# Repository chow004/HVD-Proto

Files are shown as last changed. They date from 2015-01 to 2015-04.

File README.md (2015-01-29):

# HVD-Proto
HDMI Video Divider device prototype development. Copryright DigiPen Institute of Technology.

Project development for the HVD began September, 2014. The project is considered course work for ECE310L and ECE460L.
All submission should be organized into the following sections:

Documents - This section will contain technical documentation, presentation materials, and references used during development.

Hardware - This section contains files related to hardware development mainly including eagle files.

Software - This section sontains files related to software development mainly including code files.

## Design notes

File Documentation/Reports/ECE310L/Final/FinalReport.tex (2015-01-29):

\documentclass[pdftex,12pt,a4paper]{article}

\usepackage{graphicx}
\DeclareGraphicsExtensions{.jpg}
\usepackage{float}
\usepackage[labelfont=bf]{caption}

\frenchspacing

\newcommand{\HRule}{\rule{\linewidth}{0.5mm}}

\begin{document}
\input{./title.tex}

\pagebreak
\tableofcontents
\pagebreak

%ABSTRACT
\section{Abstract}
The HVD is designed to duplicate or spatially divide display data from any HDMI signal. The hardware requirements of the HVD and image processing required by the device design will benefit from the parallel processing offered by an FPGA platform\cite{TechDoc_FPGA_Benefits}.  Specifically, the HVD will be implemented with the Cyclone IV on the DE2-115 development board paired with HDMI interface solutions offered by Analog Devices\cite{DataSheet_ADV7611, DataSheet_ADV7513, Guide_ADV7611, Guide_ADV7513}. Development concerning the design and testing of the HDMI interface PCBs and I$^2$C communication will be covered by this paper. Due to the project goals remaining unachieved, evaluation concerning design progress and future planning is also presented. 

%INTRODUCTION
\section{Introduction}

\paragraph{}
As a student we have found FPGA development and communication protocols subject of our highest interests. FPGA devices can enable engineers to use hardware to implement software applications with less concern about application specific device processing constraints. FPGA's reconfigurablility provide system flexibility and adaptability during the design phase. They have no operating system system and use parallel processing paths, giving the designer control of the architecture for processing logic \cite{TechDoc_FPGA_Benefits}.

\paragraph{}
Communication protocols are a means of communicating data between two systems or to device peripherals. The protocols are standardized meaning peripheral devices can communicate with a variety of systems. Communication protocol are essential for several computer system and can vastly improve data processing. Advancements in display protocols in particular has refined how users observe video data. HDMI 2.0, for example, increased video resolution from 1080p to 2160p \cite{Web_HDMI_2.0}. Consumers can enjoy higher resolution images and higher video refresh rates partially due to improvements in protocols. Thus protocols can serve a pivotol role in technological advancement. 

\paragraph{}
With respect to our subjects of interest, FPGA development and protocols, we prepared a design for an FPGA device that primarily relies of communication protocol implementation. This device we came to call the HVD for HDMI Video Divider.As the name suggests, the device's end use will be to spatially divide an HDMI video frame and process each division for output. The HVD will be especially suited for split screen applications. The device implementation  consists of the base FPGA platform, HDMI interface, and I$^2$C driven system intercommunication. This document will overview the system design in detail, procedures used to test the system, and analyze the progress of the device's development within the first development cycle.

%END USER APPLICATION
\section{End User Application}

\paragraph{}
The HVD shall function given standard HDMI display data from any source. This flexibility allows the device implementation opportunities in various applications. Any other HDMI output capable product, such as a DVD player, computer, or video game console, will provide dual video data with the assitance of the HVD. The HVD will exist between the source and display mediums in an application setup. The source HDMI signal will enter the HVD device to be interpreted and optionally divided before duplicated display data or divided display data is sent to respective display mediums. Figure~\ref{fig:use} is a diagram of the theoretical HVD setup for a display divided across two mediums.

% FIGURE
\begin{figure}[H]
\centering
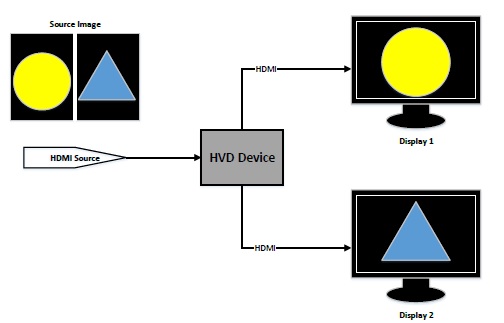
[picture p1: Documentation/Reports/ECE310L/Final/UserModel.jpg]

\caption{\textbf{Setup for dividing video across two display mediums using the HVD device}}
\label{fig:use}
\end{figure}

\paragraph{}
While the HVD can apply to an arbitrary HDMI source, the suitable applications for this device are more situational. For example, clients wouldn't have any need to divide a movie display across two TVs which may result in decreased video quality. All video applications do not benefit from the features the HVD offers, but several cases do. A split screen application has more obvious use for the HVD. Split screen  is a video technique in which the frames are spatially divided into discrete nonoverlapping images. Cooperative or comptetitve multiplayer video game applications can use this technique to incorporate multi-user designs. However, the nature of such a design allows players to 'screen peek,' a tactic where players might watch an opponent's screen to gain an unfair advantage. With the HVD, this situation can be prevented. Each user's portion of the display can be output to a separate video medium which can be moved to make the display more private to one of the users.

%SYSTEMS DESIGN
\section{Systems Design}

\paragraph{}
The HVD device requires the integration of several systems to provide complete functionality of the necessary features. This section cover the individual design and implementation of each of the HVD's major systems including the system platform, hdmi interface, and I$^2$C communications. Figure~\ref{fig:block} at the end of this section is a block diagram of the entire HVD system design.

%	FPGA PLATFORM
\subsection{FPGA Platform}

\paragraph{}
The Altera DE2-115 Development Board was selected as HVD's processing platform. Implementing the HVD on an FPGA was a easier design solution as opposed to finding an ASIC development solution that matched all the design constraints. These design constraints include support for three HDMI ports and high speed video processing. An FPGA design is suitable for the HVD's design because the highly parallel architecture they offer meet the HDMI performance requirements\cite{TechDoc_FPGA_Benefits}. The DE2-115 digital logic is programmed using the Verilog hardware descriptive language compiled and developed with Altera's toolchain, Quartus II. 

\paragraph{}
Using the DE2-115 ensures we can implement a solution for the HVD design requirements. The on-board 50 MHz clock and PLL clock generator enables the FPGA to process the high speed HDMI . The board does have SDRAM and SRAM, but these memory implementations have insufficient bandwidth to store the data fast enough\cite{UserManual_DE2}. Therefore, we will store data using the Cyclone IV FPGA embedded memory M9K blocks. The M9K blocks features configurable data width and dual-port modes necessary for storing pixel data at the required speeds\cite{TechDoc_M9K}. The HDMI protocol support a pixel clock up to 165 MHz at a resolution of 24 bits per pixel, resulting in the necessity to simultaneously read and write data at almost 4 Gbps\cite{TechDoc_HDMI_Spec}.

\paragraph{}
While the DE2-115 does not provide an HDMI interface solution, the HSMC is a high-speed header that can provide a sufficient amount of GPIO lines to the Cyclone IV for our own integration of an HDMI interface. Paired with the a Terasic GPIO Daughter Board, we HSMC connects to three more GPIO headers\cite{UserManual_THDB-HTG} which can be used to communicate with three HDMI interfaces.

%	HDMI Interface
\subsection{HDMI Interface}

\paragraph{}
The HDMI interface will be implemented using Analog Devices chip solutions. The ADV7611 implements HDMI receiving interface while two ADV7615 will implement each HDMI transmission interface. The HDMI receiver interface translates the differential signals from an HDMI source into 24 parallel pixel data signals\cite{DataSheet_ADV7611}. Audio data is also provided and interpreted by the HDMI interface but is not being implemented in HVD version 1.0. The transmitter interfaces translates 24 parallel pixel data lines into differential signals\cite{DataSheet_ADV7513}. The chips are configured through their main I$^2$V ports which control registers and protocol data such as the info frame or extended display identification data, EDID. Protocol information is essential for identifying and controlling the HDMI configuration of the source device\cite{TechDoc_HDMI_Spec}.

%	SYSTEM COMMUNICATIONS
\subsection{Communications}

\paragraph{}
The DE2-115 must establish communication with the HDMI interfaces. There will be an I$^2$C protocol port generated using the FPGA's digital logic for each interface. The logic of the Verilog module for the I$^2$C protocol is implemented using a finite state machine architecture. The I$^2$C module generates the protocol's serial clock of approximately 390 KHz from the 50 MHz main clock on the DE2-115. The module's logic is handled in two major blocks functioning off of a logic clock and serial clock. State machine transition and serial data is processed on the logic clock while serial clock ticks and byte transaction and processed on the serial clock. The logic and serial clock are generated so that a logic process step will execute between each serial clock cycle so that the data line is correctly set before the serial clock indicates data is valid on the bus. Figure~\ref{fig:sm} shows the state diagram for the I$^2$C module. Both logic block functionality are dependent on this state machine.

% FIGURE
\begin{figure}[H]
\centering
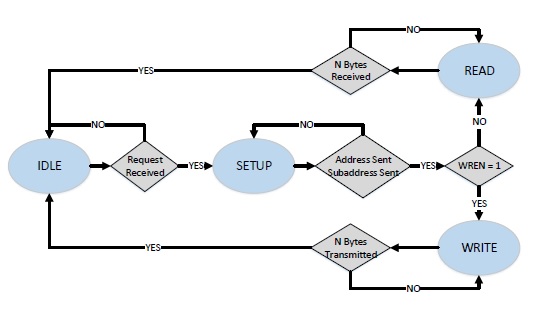
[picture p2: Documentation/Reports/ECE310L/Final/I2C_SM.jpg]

\caption{\textbf{I$^2$C module finite state machine}}
\label{fig:sm}
\end{figure}

\paragraph{}
The Cyclone IV FPGA acts as the master in the I$^2$C protocol while each register map on the HDMI interfaces are slaves. Since each HDMI interface will have its own dedicated I$^2$C port we can assume the default slave address configurations on each interface.  Each slave device is accessed with a 7-bit address, a R/W bit indicating the nature of the transaction, and an 8-bit sub-address within the register map. The read and write procedures for the HDMI receiver are depicted in Figure~\ref{fig:i2c}\cite{Guide_ADV7611}. The HDMI transmitter is programmed via I$^2$C in the same manner with different register maps.

% FIGURE
\begin{figure}[H]
\centering
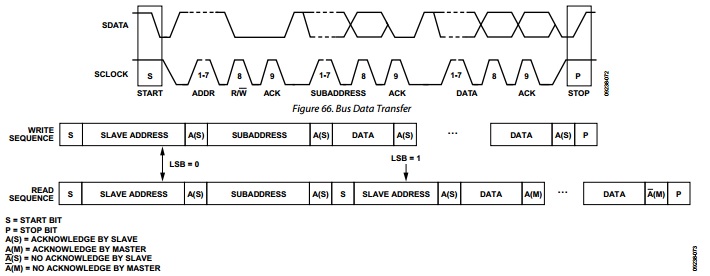
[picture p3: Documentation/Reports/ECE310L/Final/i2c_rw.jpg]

\caption{\textbf{I$^2$C read and write sequence and bus data signaling. An ACK is indicated by pulling the SDATA line low and a NACK is indicated by pulling the SDATA line high.}}
\label{fig:i2c}
\end{figure}

%	PCB INTEGRATION
\subsection{PCB Integration}

\paragraph{}
To integrate the HDMI interfaces with the DE2-115 the HDMI chips must be housed on a PCB to interface with small chip package. Each HDMI interface PCB will connect to the DE2-115 through a GPIO header on the HSMC to GPIO daughter board. Eagle schematics for the HDMI receiver PCB are located in hdmi\_receiver.sch. Care was taken to include several termination resistors and decoupling capacitors in order to maintain the interface system stability. A 3-layer PCB was design with an internal GND plane and percautions were taken to keep the HDMI differential signals parallel and similar in length. The HDMI transmitter PCBs will have a similar design to the HDMI receiver PCB. Having separate PCB designs for the transmitter and receivers provides individual control over each interface and may simplify component upkeep with separated designs.

%	BLOCK DIAGRAM
\subsection{Block Diagram}

% FIGURE
\begin{figure}[H]
\centering
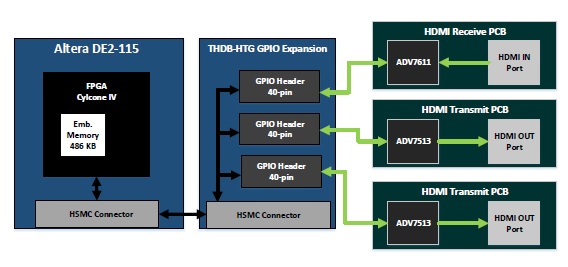
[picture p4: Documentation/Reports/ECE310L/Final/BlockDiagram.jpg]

\caption{\textbf{HVD systems block diagram}}
\label{fig:block}
\end{figure}

%RESULTS
\section{Results}

%	TIMELINE
\subsection{Timeline}

The past development cycle for the HVD is illustrated in the timeline in Figure~\ref{fig:time}.

% FIGURE
\begin{figure}[H]
\centering
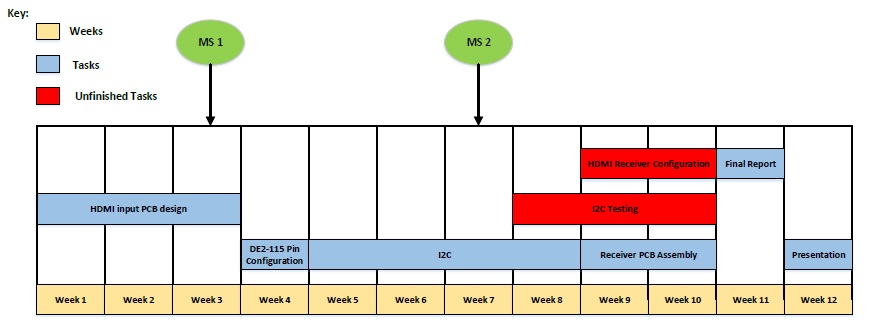
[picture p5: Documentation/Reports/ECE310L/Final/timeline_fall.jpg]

\caption{\textbf{Development timeline}}
\label{fig:time}
\end{figure}

%	HDMI RECEIVE INTERFACE
\subsection{HDMI Receive Interface}

\paragraph{}
This development cycle focused on the HDMI receive interface implementation including the PCB design, testing, and DE2-115 I$^2$C communication. The receiver was developed first in order to avoid unnecessary development requirements to test the HDMI interface. Ideally to test the HDMI transmit functionality we would ultimately want to transmit a video frame. Instead of having the FPGA generate a video frame, establish a the receiver to acquire a frame instead for later output reduced the software development.

\paragraph{}
The eagle design files for the HDMI receiver PCB are hdmi\_receiver.sch and hdmi\_receiver.brd. This prototype serve as a sufficient test board for identifying early design errors. One such error was already discovered; the footprint for the DC power jack is incorrect making the barrel receptacle impossible to solder to the board without modifications. Further testing is required to verify the functionality of this board which wasn't achieved during this development cycle.

%	I2C PROTOCOL
\subsection{I$^2$C Protocol}
The I$^2$C protocol is essential for controlling the HDMI receive interface using the DE2-115. The I$^2$C module was implemented in Verilog and tested through several mediums. First, Alter'a ModelSim IDE was used to verify the module could be instantiated and successfully produce the desired waveforms in simulation. The real signal generation of the module was observed and checked using oscilloscopes. Some oscilloscope waveform samples are shown and described in Figures~\ref{fig:osc_tx} and~\ref{fig:osc_rx}. This also verified that the pin configurations over the HSMC to GPIO daughter board were correct and functional. Finally, Link Instruments MSO-19.2 with a built in I$^2$C protocol interpreter was used to confirm the I$^2$C module signals were successfully interpreted to comply to the I$^2$C standard. 

% FIGURE
\begin{figure}[H]
\centering
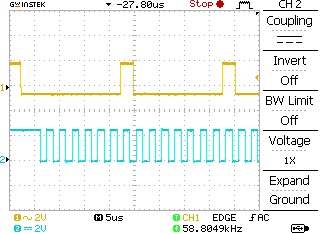
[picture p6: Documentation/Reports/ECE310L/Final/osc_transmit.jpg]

\caption{\textbf{Screen captured from oscilloscope reading I$^2$C data. The top signal is the SDA and the bottom is SCL.A write sequence is depicted in the captured image. First the SDA is pulled low while the SCL signal is high to indicate a START condition. This enable the generated of the I$^2$C serial clock signal which SCL is connected to. The first data transmitted across the SDA line is the slave address, which in this case is 0x1 in 7-bits. After the 7th bit is transmitted the R/W bit which is zero for a write sequence is sent. On 9th the SCL clock pulse, the SDA line is set to high impedance to acquire an acknowledge input from the slave device. In this case, there is no slave device connected so the SDA remains unchanged. Afterward the subaddress 0x4 is sent in 8-bits in the same fashion. }}
\label{fig:osc_tx}
\end{figure}

% FIGURE
\begin{figure}[H]
\centering
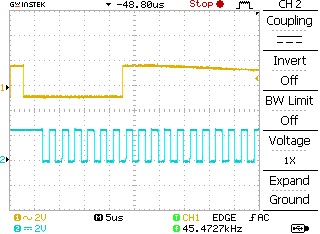
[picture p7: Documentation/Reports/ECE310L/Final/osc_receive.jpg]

\caption{\textbf{Screen captured from oscilloscope reading I$^2$C data. The top signal is the SDA and the bottom is SCL.A read sequence is depicted in the captured image. Before a read transaction, the subaddress pointer must be set by a previous write transaction. First the SDA is pulled low while the SCL signal is high to indicate a START condition. The first data transmitted across the SDA line is the slave address, which in this case is 0x1 in 7-bits. After the 7th bit is transmitted the R/W bit which is one for a read sequence is sent. ON the 9th SCL clock pulse, the SDA line is set to high impedance to acquire an acknowledge input from the slave deivce. In this case, there is no slave device connected so the SDA remains mostly unchanged. Afterwards the SDA remains set to high impedance to accept input on the SDA line. The SDA line is then only controlled by the master when asserting an ACK or NACK. This signal receives no input but because the SDA line is left at high impedance there is a noticeable decay in the signal. }}
\label{fig:osc_rx}
\end{figure}

\paragraph{}
The simulation and oscilloscope tests and check were successful but the test data offered by the MSO-19.2 gave questionable data that didn't completely confirm our I$^2$C module conformity to the standard protocol. A lack of explicit documentation on the data presented by the I$^2$C interpreter user interface, incorrect signal timing values, and some unexpected protocol behavior makes it so the test in not a perfect verification of the I$^2$C protocol correctness. A sample of MSO-19.2 data is shown and described in Figure~\ref{fig:mso}.

% FIGURE
\begin{figure}[H]
\centering
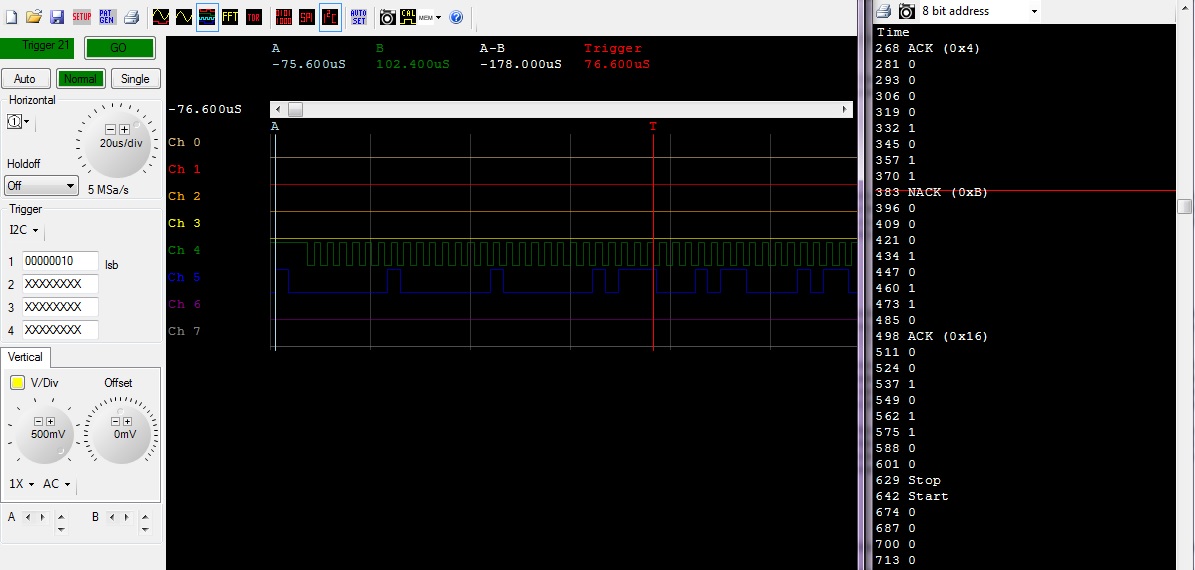
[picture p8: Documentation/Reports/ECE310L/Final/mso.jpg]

\caption{\textbf{This is MSO data from an I$^2$C write sequence. Channel 4 is the SCL signal and Channel 5 is the SDA signal. The I$^2$C interpreted data is shown in a console window to the right. Start and Stop condition are detected successfully. The data bytes represented in the console window are also correct. However the timing units in microseconds are for some reason off by a factor of 10. Each clock cycle should take approximately 2.5 microseconds while the MSO data shows approximately 25 microseconds. There also is a matter concerning the NACK. The MSO interpeter should generate acknowledge signal for valid I$^2$C data but after receiving a 0xB data byte in this case it generated a NACK. The cause for this is unknown. }}
\label{fig:mso}
\end{figure}

%ANALYSIS
\section{Analysis}

%	TESTING
\subsection{Testing}

\paragraph{}
The HDMI receiver PCB and I$^2$C protocol tests are largely incomplete. The goal for integrated these two systems was also not achieved. Some lack of development foresight in development time led to delays and deviation from the original time line became inevitable. Since the I$^2$C protocol correctness isn't completely verified, we will have to examine if its current implementation is able to properly communicate with the HDMI receive PCB. Examining the functionality of the PCB, ADV7611 HDMI receiver, and the correctness of the I$^2$C protocol at the same time can lead to difficult debugging scenarios involving multiple variables. Unless more investment is made to further test the I$^2$C protocol with additional testing hardware, the cluttered testing scenario may be inevitable.

%	DEVELOPMENT TIME
\subsection{Development Time}

\paragraph{}
Setbacks in the initial development cycle will propagate through to the next. Expected project goals must be re-evaluated. It is an end design goal to be able to process and divide a single HDMI signal into two separate signals. In order to fully implement the hardware and integrate the system, time to development image processing requirements may be sacrificed. The image processing logic, while it is an essential part of the HVD's ideal application, must be the first feature to be dropped from expected implementations in the next development cycle because it reliant on functioning hardware and complete system integration. A proposed time line for next development cycle is shown in Figure~\ref{fig:newtime}. Notice that there is no time reserved for the image processing algorithms necessary for the HVD goal application.

% FIGURE
\begin{figure}[H]
\centering
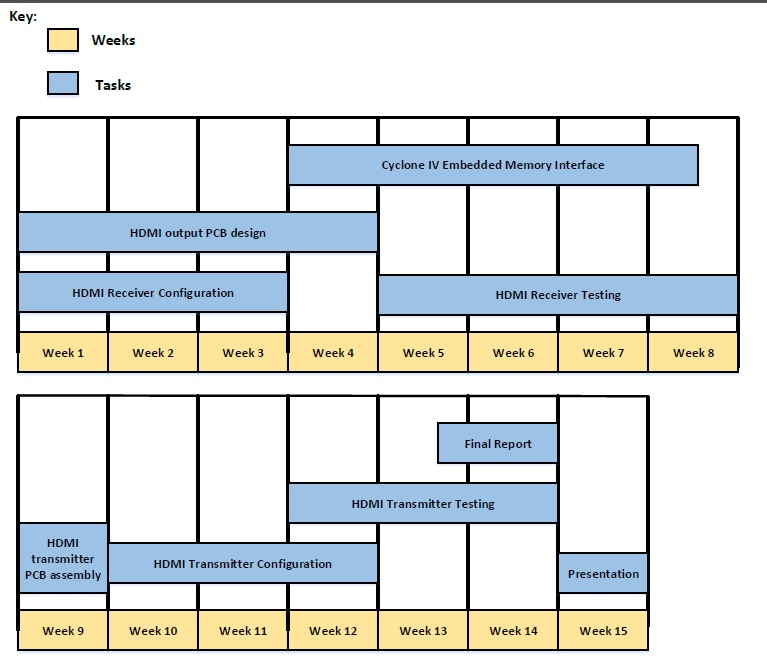
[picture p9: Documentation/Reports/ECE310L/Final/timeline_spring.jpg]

\caption{\textbf{Next cycle development timeline}}
\label{fig:newtime}
\end{figure}

%	BUDGET
\subsection{Budget}

\paragraph{}
The cost reports for this development cycle was rather high. The PCB fabrication expense for HDMI receiver consumed most of the allowed budget. In order to improve the HVD cost efficiency, future versions should be reduced from a 3-layer to 2-layer board. This will present more design constraints in order to ensure signal integrity. Examining current design faults in the HDMI receive PCB will lend insight when designing the HDMI transmit PCB.

%CONCLUSION
\section{Conclusion}

\paragraph{}
Results of this development cycle are less than optimal. Several pivitol tasks and goals that were not completely satisfied and others were pushed back resulting. However, steady though unideal progress on the development of the HVD systems has deviated little from the original implementation designs. We are confident that the design plans for the HVD remains sound.

\paragraph{}
Overall, the major systems that were suppose to be complete within this cycle still need to be verified and tested. Once all the issues are determined, they can be addressed in future design iterations. While development on the HDMI transmit interface was never achieved, it's similarity to the HDMI receive interface means and problems encountered in devloping the receiver can be avoided when designing the transmitter. The I$^2$C protocol module on the DE2-115 will also function in communication with the transmitter. 

\paragraph{}
In the following cycle, once the previous tasks are completed. A quick rework of the receiver PCB, prototype of the transmitter PCB and I$^2$C integration should be achievable. The remaining time can be spent working on the HDMI configuration software and memory logic on the Cyclone IV. The image processing development has been delayed, but focus on the HVD hardware and interface systems is an absolute priority.

\pagebreak
%ACKNOWLEDGEMENTS
\section{Acknowledgements}

\paragraph{}
We would like to acknowledge the following persons, whose contributions and guidance made the development and execution of this project possible.
\newline
\newline
Lukas van Ginneken for instructing and assisting in planning the project, identifying design constraints, and providing development solutions. Jeremy Thomas for instructing, offering guidance on engineering practices, and encouragement that helped keep us motivated. Christopher Theriault for managing the project budget, acquiring necessary resources, and providing test tools. Nicholas Rivera for sharing his experience and knowledge in embedded systems designs. And Johnny Sim for sharing his experience and knowledge of Altera's FPGA development software.
\newline
\newline
Thank you for all of your support.

%References
\bibliographystyle{ieeetr}
\bibliography{Citation}

\end{document}

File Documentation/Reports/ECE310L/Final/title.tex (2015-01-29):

\begin{titlepage}
\begin{center}

%Title
\HRule \\[0.5cm]
{\huge \bfseries HVD-1\\[0.5cm]}
\HRule \\[1.0cm]

\textsc{\LARGE HDMI Video Divider ver 1.0}\\
[1.5cm]

%Engineers
\begin{minipage}{0.9\textwidth}
\begin{flushleft} \large
{\bfseries Engineer:}\\
\emph{Cassandra \textsc{Chow}}
\end{flushleft}
\end{minipage}
%Instructors
\begin{minipage}{0.9\textwidth}
\begin{flushright} \large
{\bfseries Instructors:}\\
\emph{Lukas \textsc{van Ginneken}}

\emph{Jeremy \textsc{Thomas}}

\emph{Christopher \textsc{Theriault}}
\end{flushright}
\end{minipage}

\vfill

%Bottom of Page
{\large DigiPen Institute of Technology}\\
{\large Department of Computer Engineering}\\
{\large ECE 310L, Fall 2014}\\
{\large Revision: 1.0}

\end{center}
\end{titlepage}

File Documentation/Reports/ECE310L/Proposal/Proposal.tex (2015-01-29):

\documentclass[12pt]{article}
\pagestyle{plain}
\linespread{2}

% Document
\title{HDMI Divider}
\author{Cassandra Chow}

% Declarations
\usepackage{graphicx}
\DeclareGraphicsExtensions{.jpg}

\frenchspacing
\usepackage{indentfirst}
\usepackage{fullpage}
\usepackage{float}

\begin{document}
\maketitle

% ABSTRACT
\begin{abstract}
With the detailed project we will strive to design an embedded system that will enable the user to divide a primary high-definition multimedia interface (HDMI) display source into two separate outputs that each display half of the primary display. The application of this device if focused at enabling video game players to assign parts of the game display to other dedicated displays which can be useful for multiplayer games designed with split-screen gameplay. To do this, our product will need to accept HDMI input frames, divide that input into two separate output frames, and process the output frame to suit their individual displays. 
\end{abstract}

\pagebreak
\tableofcontents

% INTRODUCTION
\pagebreak
\section{Introduction}

Our product, which we will call an HDMI Divider for now, will be designed to give its user a solution to dividing split-screens that is not otherwise offered by the application or display hardware itself. The application of the HDMI splitter is illustrated in Figure~\ref{fig:concept}. Because the HDMI divider will be able to accept HDMI signals from an arbitrary source device, it's application can be utilized across any platform using HDMI output. Giving consumers the option of dividing their display can enhance the experience of video game players especially in competitive gameplay. Where players are competing, it is in the best interest of each user to win against the other in some manner but a split-screen setup prevents the players from concealing their actions from the other. Another reason players might find this device attractive is just the ability to expand their split portion of the screen to a larger display.

\begin{figure}[H]
\centering
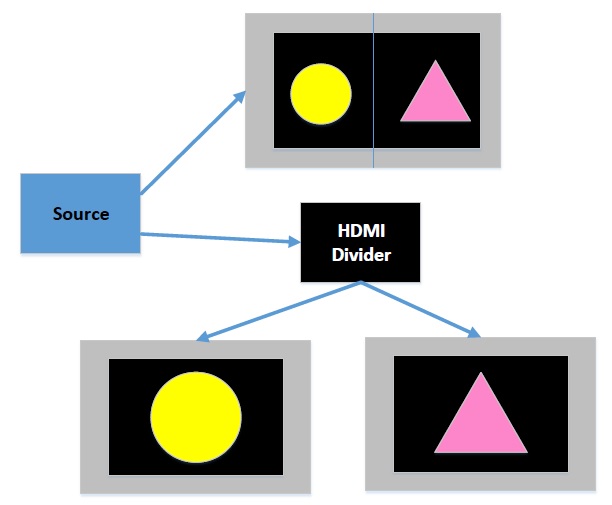
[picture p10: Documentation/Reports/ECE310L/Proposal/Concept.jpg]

\caption{Represents use model concept of the HDMI divider dividing a split-screen into two dedicated displays}
\label{fig:concept}
\end{figure}

This project also acts as a challenging learning experience to an undergraduate student. Since we will be utilizing the digital logic on a field-programmable gate array (FPGA) to accomplish our device implementation, we will not only become more familiar with FPGA applications but also obtain a better grasp on embedded system architecture and the HDMI protocol specification. Most projects of interest to us required in-depth knowledge in protocols that are widely used in various electronics, therefore a project which includes development on the HDMI is the main reason for undertaking this task. All of the above benefits will be sought out in order to improve our design capabilities as an engineer. 

% METHODS, TECHNIQUES, and DESIGN
\section{Methods, Techniques, and Design}

% DESIGN CONSIDERATIONS
\subsection{Design Considerations}

To understand the requirements for our project we must examine our resource requirments which includes knowing what data we are acquiring, how the data is being acquired, and what our device will do with that data. For our application model we will require the display data from some external source which will be transmitted via the HDMI interface. The received display data must be processed and then output across two individual displays. Our target display format is the standard HDTV configuration which supports a resolution of 1920x1080p. The platform we decided on to implement our design is an FPGA. FPGAs are known for being able to perform signal processing quickly which is critical in display applications. The specific development platform we will be using is Altera's DE2-115 Development and Education board.The DE2 provides us with sufficient means in accomplishing our project requirements while also being flexible to future changes.

% HDMI DISPLAY
\subsection{HDMI Display}

According to the HDMI specification, there are three data channels used to transmit pixel data typically at a resolution of 24 bits per pixel, 8 bits per channel. The HDMI interface has a pixel clock that functions at a maximum of 165 MHz \cite{Ref_HDMI_Spec}. The DE2 can support the necessary switching speed on it's I/O lines but the on-board SRAM and SDRAM have insufficient bandwidth capabilities to store the data fast enough. We will therefore be writing to the embedded memory on the FPGA chip allowing us to take advantage of the speed capabilities on the FPGA. There are only 486 Kbytes of embedded memory on the Cyclone IV DE2 FPGA chip \cite{Ref_Memory_Block}, so we cannot store entire frames but this is sufficient space to store the each line of data for each input and output frame until it it is processed. Then by using a simple image rescaling algorithm, such as nearest neighbor or interpolation, we can als ensure we are able to resize the image properly even if we cannot send and receive an entire frame at once.

There is no onboard solution for implementing the HDMI protocol on the DE2 board, therefore we will being using HDMI transmitter and HDMI receiver chipsets. Each selected chipset requires approximately 32 I/O lines \cite{Ref_HDMI_Rx} to interface with the DE2 but the DE2 board only has 36 GPIO pins mapped to the the Cyclone IV \cite{Ref_DE2}. However, we can expand the number of GPIO pins available by connection an expansion board to the DE2's High-Speed Mezzanine Connector (HSMC), giving us access to another three GPIO headers. Since we only need 3 HDMI interface, 1 input and 2 outputs, we will only have enough GPIO pins available if we use the HSMC GPIO expansion daughter card. To implement the HDMI chipsets and connection, we'll be designing a PCB for each to interface with the DE2 though the GPIO expansion. Our implementation for our device is illustrated by the system block diagram in Figure~\ref{fig:block}.

\pagebreak

% BLOCK DIAGRAM
\subsection{System Block Diagram}

\begin{figure}[H]
\centering
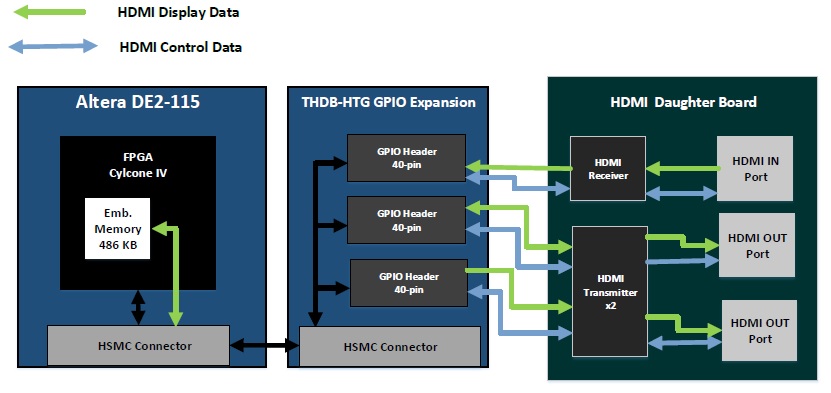
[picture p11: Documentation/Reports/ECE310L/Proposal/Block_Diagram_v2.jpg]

\caption{Block Diagram of device implementation}
\label{fig:block}
\end{figure}

\pagebreak

% PARTS LIST
\section{Parts List}

These are the primary components required for our HDMI Divider implementation

\begin{itemize}
\item Altera DE2-115 Education and Development Board \cite{Ref_DE2}
\item THDB-HTG GPIO daughter board \cite{Ref_GPIO_daughter}
\item ADV7611 HDMI Receiver \cite{Ref_HDMI_Rx}
\item AD9389B HDMI Transmitter x2 \cite{Ref_HDMI_Tx}
\end{itemize}

% TIMELINE
\section{Timeline}

Figure~\ref{fig:timeline} is the task timeline we have set for ourselves over the next 12 weeks of development. By the end of 12 weeks we should be able to confirm HDMI input and output functionality including the memory architecture requirements. Notice that we are not going to be working on the image processing required for dividing and resizing the display output yet, just establishing the protocol functionality on the FPGA.

\begin{figure}[H]
\centering
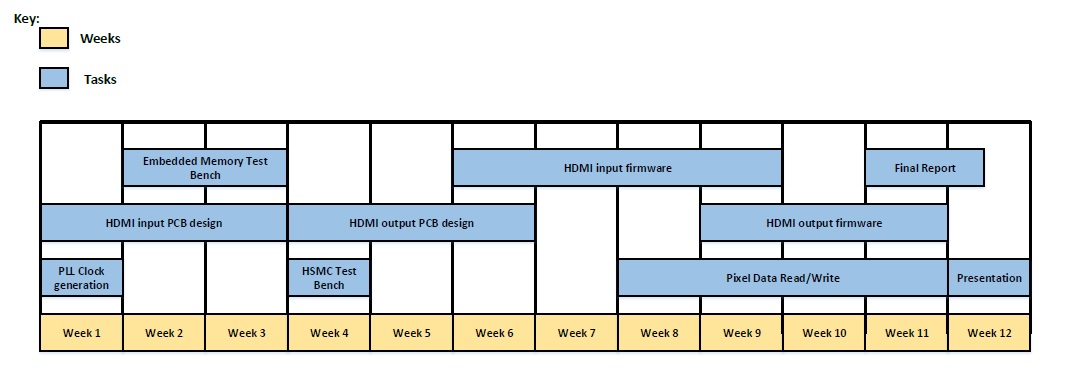
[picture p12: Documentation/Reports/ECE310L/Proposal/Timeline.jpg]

\caption{Timeline for development tasks}
\label{fig:timeline}
\end{figure}

\begin{description}
\item[PLL Clock Generation] Configuring the PLL on the FPGA to generate desired clock rates for processing
\item[HDMI Input PCB Design] Designing the PCB for the daughter card implementing the HDMI input port and interface
\item[HDMI Output PCB Design] Designing the PCB for the daughter card implementing the HDMI output port and interface
\item[Embedded Memory Test Bench] Configuring embedded memory system and testing read/write functionality
\item[HSMC Signal Test Bench] Configuring signal I/O over the HSMC to GPIO bus and testing functionality
\item[HDMI Input Firmware] Developing FPGA digital logic for receiving HDMI display data
\item[HDMI Output Firmware] Developing FPGA digital logic for transmitting HDMI display data
\item[Pixel Data Read/Write] Developing the read/write process for storing display data in memory
\item[Final Report] Compiling final project results into a report document
\item[Presentation] Preparing and delivering presentation of project results
\end{description}

\section{Citation}
\bibliographystyle{plain}
\bibliography{Citation}

\end{document}

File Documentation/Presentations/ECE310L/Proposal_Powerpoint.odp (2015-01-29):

## FPGA HDMI Display Divider

DigiPen Institute of Technology

Fall 2014

ECE 310L

Presented by Cassandra Chow

## Project Goals

- Learning FPGA architecture and application
- HDMI Protocol
  Mission Statement:
  To create a device that enables the user to divide their HDMI display into separate parts and delegate to these parts their own dedicated displays.

## High Concept

## Split-screen display

## Two dedicated displays

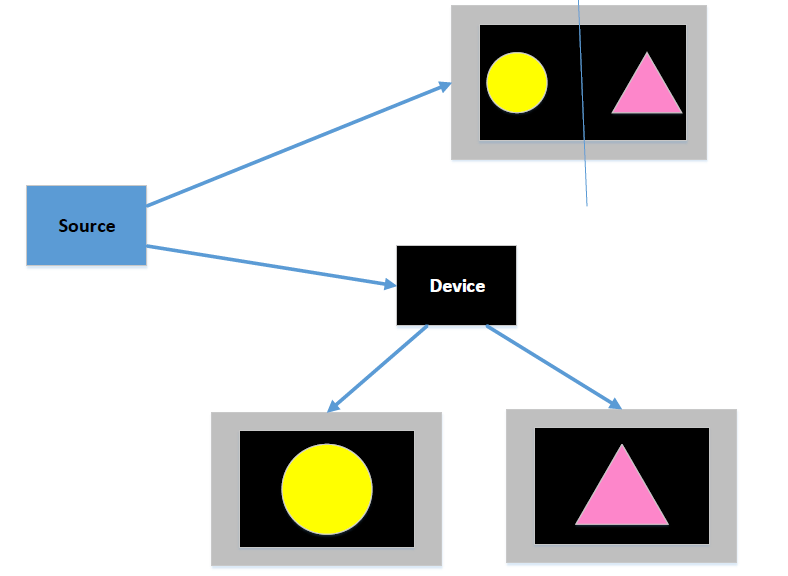
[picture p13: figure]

## FPGA Platform

- High speed video processing
- A little processing on a lot of data
- Requires building of analog components from scratch.

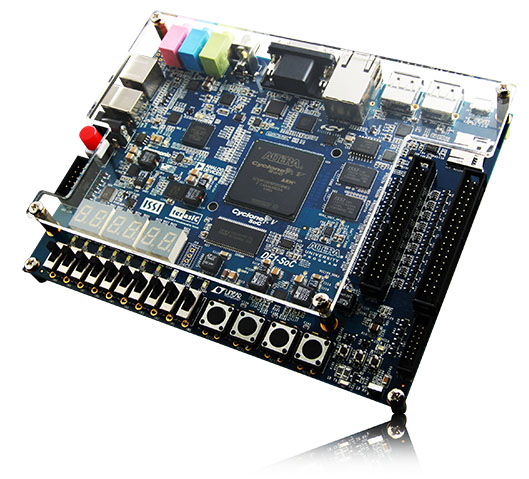
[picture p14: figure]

## HDMI Differential Signaling

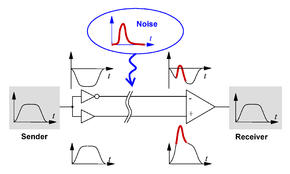
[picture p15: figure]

## Device Design

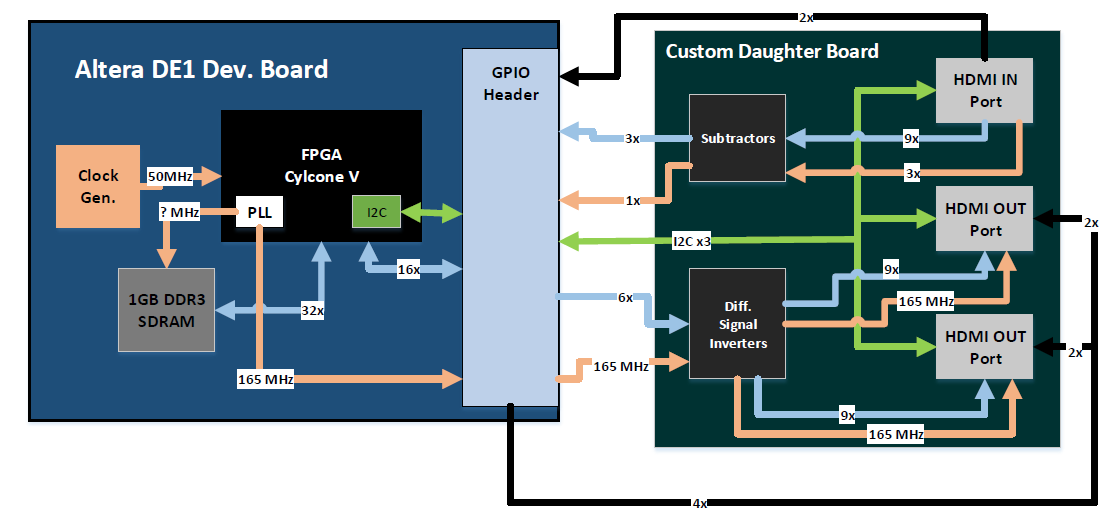
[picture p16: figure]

## Time Line (13 weeks)

- PLL & DDR3 SDRAM firmware (2 weeks)
- HDMI output prototype & firmware (2 weeks)
    > Debugging & Testing (1 week)
- HDMI input prototype & firmware (2 weeks)
    > Debugging & Testing (2 weeks)
- PCB design & fabrication (2 weeks)
- Final Report & Polish ( 2 weeks)

## Questions?

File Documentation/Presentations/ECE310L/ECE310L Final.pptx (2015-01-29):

## HDMI Video Divider HVD-1

DigiPen Institute of Technology
Fall 2014
Cassandra Chow

## Project Motivations

- FPGA Development
- Hardware implementation of software
- Reconfigurable
- Communication Protocols
- Rules that define format of data exchanges

## Project Concept

- An FPGA based device designed to duplicate or spatially divide display data from any HDMI signal

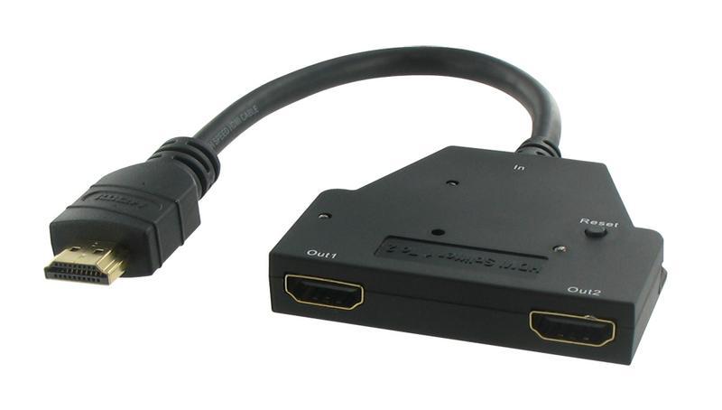
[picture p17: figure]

## HVD Use Model

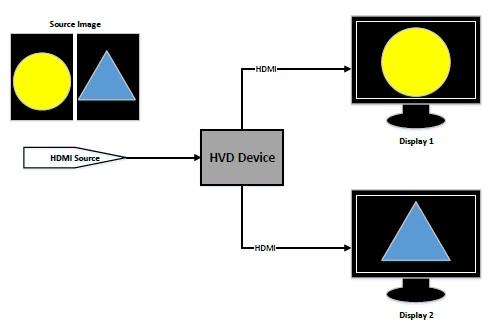
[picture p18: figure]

## Implementation

- Altera DE2-115
- Analog Devices HDMI Interface ASIC
- HSMC to GPIO daughter board
- I2C protocol intercommunication

## System Block Diagram

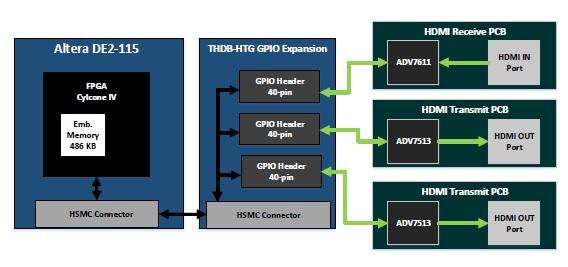
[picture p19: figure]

## I2C Communication

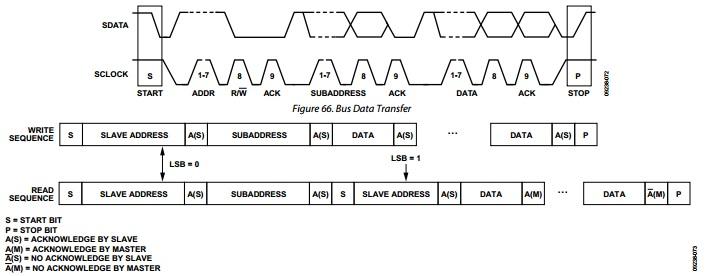
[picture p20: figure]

## I2C as a Finite State Machine

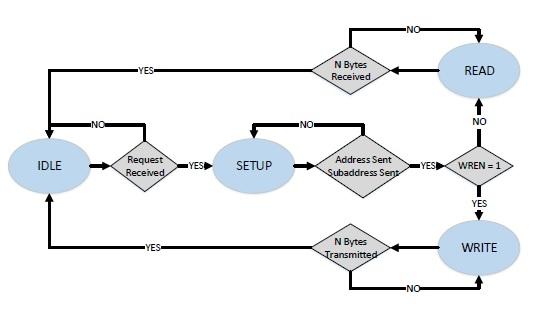
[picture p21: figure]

## Develop, Test, Debug

- Quartus II, Verilog HDL
- ModelSim waveform view
- Oscilloscope Tests
- MSO protocol interpreter

## Oscilloscope Test Data

Write Read

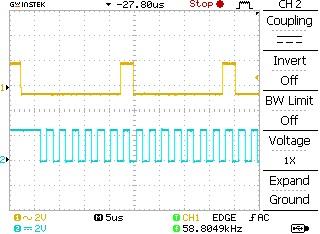
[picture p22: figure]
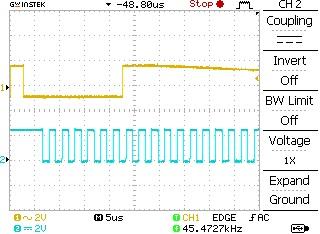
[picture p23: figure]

## MSO Test Data

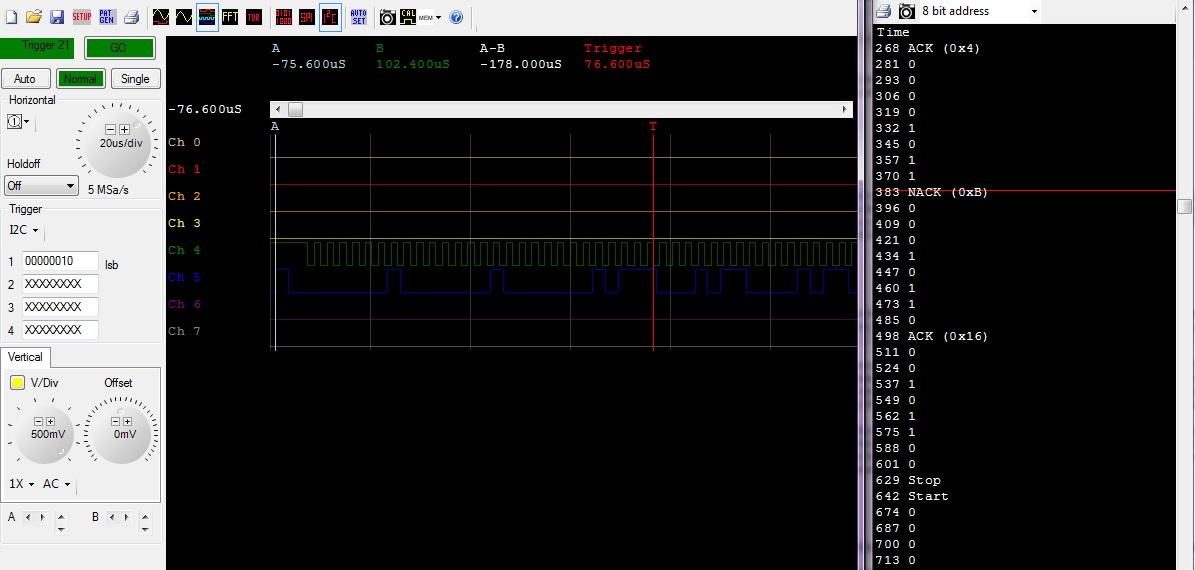
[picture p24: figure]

## HDMI Receiver PCB

- Eagle

## System Integration

- Requires verifying I2C communication
- Points of uncertainty hinder testing
Possible bugs
- I2C is incorrect
- PCB is flawed

Debug Solution: Acquire reliable I2C source

## Fall Timeline


## Next Semester

- Test and Debug
- HDMI Transmitter PCB
- DE2-115 Memory Interface
- HDMI Receive/Transmit Software

## Acknowledgements

- Lukas van Ginneken
- Jeremy Thomas
- Christopher Theriault
- Nicholas Rivera
- Johnny Sim

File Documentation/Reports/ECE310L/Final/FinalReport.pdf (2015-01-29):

# HVD-1

HDMI Video Divider ver 1.0

### Engineer: Cassandra Chow Instructors:

Lukas van Ginneken

### Jeremy Thomas Christopher Theriault

### DigiPen Institute of Technology Department of Computer Engineering ECE 310L, Fall 2014 Revision: 1.0

## Contents

1 Abstract | 2
2 Introduction | 2
3 End User Application | 3
4 Systems Design | 4
5 Results | 8
6 Analysis | 12
7 Conclusion | 14
8 Acknowledgements | 15

1

## 1 Abstract

The HVD is designed to duplicate or spatially divide display data from any HDMI signal. The hardware requirements of the HVD and image processing required by the device design will benefit from the parallel processing offered by an FPGA platform[1]. Specifically, the HVD will be implemented with the Cyclone IV on the DE2-115 development board paired with HDMI interface solutions offered by Analog Devices[2, 3, 4, 5]. Development concerning the design and testing of the HDMI interface PCBs and I²C communication will be covered by this paper. Due to the project goals remaining unachieved, evaluation concerning design progress and future planning is also presented.

## 2 Introduction

As a student we have found FPGA development and communication protocols subject of our highest interests. FPGA devices can enable engineers to use hardware to implement software applications with less concern about application specific device processing constraints. FPGA’s reconfigurablility provide system flexibility and adaptability during the design phase. They have no operating system system and use parallel processing paths, giving the designer control of the architecture for processing logic [1].

Communication protocols are a means of communicating data between two systems or to device peripherals. The protocols are standardized meaning peripheral devices can communicate with a variety of systems. Communication protocol are essential for several computer system and can vastly improve data processing. Advancements in display protocols in particular has refined how users observe video data. HDMI 2.0, for example, increased video resolution from 1080p to 2160p [6]. Consumers can enjoy higher resolution images and higher video refresh rates partially due to improvements in protocols. Thus protocols can serve a pivotol role in technological advancement.

With respect to our subjects of interest, FPGA development and protocols, we prepared a design for an FPGA device that primarily relies of communication protocol implementation. This device we came to call the HVD for HDMI Video Divider.As the name suggests, the device’s end use will be to spatially divide an HDMI video frame and process each division for output. The HVD will be especially suited for split screen applications. The device implementation consists of the base FPGA platform, HDMI interface, and I²C driven system intercommunication. This document will overview the

2

system design in detail, procedures used to test the system, and analyze the progress of the device’s development within the first development cycle.

## 3 End User Application

The HVD shall function given standard HDMI display data from any source. This flexibility allows the device implementation opportunities in various applications. Any other HDMI output capable product, such as a DVD player, computer, or video game console, will provide dual video data with the assitance of the HVD. The HVD will exist between the source and display mediums in an application setup. The source HDMI signal will enter the HVD device to be interpreted and optionally divided before duplicated display data or divided display data is sent to respective display mediums. Figure 1 is a diagram of the theoretical HVD setup for a display divided across two mediums.


Figure 1: Setup for dividing video across two display mediums using the HVD device

While the HVD can apply to an arbitrary HDMI source, the suitable applications for this device are more situational. For example, clients wouldn’t have any need to divide a movie display across two TVs which may result in decreased video quality. All video applications do not benefit from the

3

features the HVD offers, but several cases do. A split screen application has more obvious use for the HVD. Split screen is a video technique in which the frames are spatially divided into discrete nonoverlapping images. Cooperative or comptetitve multiplayer video game applications can use this technique to incorporate multi-user designs. However, the nature of such a design allows players to ’screen peek,’ a tactic where players might watch an opponent’s screen to gain an unfair advantage. With the HVD, this situation can be prevented. Each user’s portion of the display can be output to a separate video medium which can be moved to make the display more private to one of the users.

## 4 Systems Design

The HVD device requires the integration of several systems to provide complete functionality of the necessary features. This section cover the individual design and implementation of each of the HVD’s major systems including the system platform, hdmi interface, and I²C communications. Figure 4 at the end of this section is a block diagram of the entire HVD system design.

### 4.1 FPGA Platform

The Altera DE2-115 Development Board was selected as HVD’s processing platform. Implementing the HVD on an FPGA was a easier design solution as opposed to finding an ASIC development solution that matched all the design constraints. These design constraints include support for three HDMI ports and high speed video processing. An FPGA design is suitable for the HVD’s design because the highly parallel architecture they offer meet the HDMI performance requirements[1]. The DE2-115 digital logic is programmed using the Verilog hardware descriptive language compiled and developed with Altera’s toolchain, Quartus II.

Using the DE2-115 ensures we can implement a solution for the HVD design requirements. The on-board 50 MHz clock and PLL clock generator enables the FPGA to process the high speed HDMI . The board does have SDRAM and SRAM, but these memory implementations have insufficient bandwidth to store the data fast enough[7]. Therefore, we will store data using the Cyclone IV FPGA embedded memory M9K blocks. The M9K blocks features configurable data width and dual-port modes necessary for storing pixel data at the required speeds[8]. The HDMI protocol support a pixel clock

4

up to 165 MHz at a resolution of 24 bits per pixel, resulting in the necessity to simultaneously read and write data at almost 4 Gbps[9].

While the DE2-115 does not provide an HDMI interface solution, the HSMC is a high-speed header that can provide a sufficient amount of GPIO lines to the Cyclone IV for our own integration of an HDMI interface. Paired with the a Terasic GPIO Daughter Board, we HSMC connects to three more GPIO headers[10] which can be used to communicate with three HDMI interfaces.

### 4.2 HDMI Interface

The HDMI interface will be implemented using Analog Devices chip solutions. The ADV7611 implements HDMI receiving interface while two ADV7615 will implement each HDMI transmission interface. The HDMI receiver interface translates the differential signals from an HDMI source into 24 parallel pixel data signals[2]. Audio data is also provided and interpreted by the HDMI interface but is not being implemented in HVD version 1.0. The transmitter interfaces translates 24 parallel pixel data lines into differential signals[3]. The chips are configured through their main I²V ports which control registers and protocol data such as the info frame or extended display identification data, EDID. Protocol information is essential for identifying and controlling the HDMI configuration of the source device[9].

### 4.3 Communications

The DE2-115 must establish communication with the HDMI interfaces. There will be an I²C protocol port generated using the FPGA’s digital logic for each interface. The logic of the Verilog module for the I²C protocol is implemented using a finite state machine architecture. The I²C module generates the protocol’s serial clock of approximately 390 KHz from the 50 MHz main clock on the DE2-115. The module’s logic is handled in two major blocks functioning off of a logic clock and serial clock. State machine transition and serial data is processed on the logic clock while serial clock ticks and byte transaction and processed on the serial clock. The logic and serial clock are generated so that a logic process step will execute between each serial clock cycle so that the data line is correctly set before the serial clock indicates data is valid on the bus. Figure 2 shows the state diagram for the I²C module. Both logic block functionality are dependent on this state machine.

5


Figure 2: I²C module finite state machine

The Cyclone IV FPGA acts as the master in the I²C protocol while each register map on the HDMI interfaces are slaves. Since each HDMI interface will have its own dedicated I²C port we can assume the default slave address configurations on each interface. Each slave device is accessed with a 7-bit address, a R/W bit indicating the nature of the transaction, and an 8-bit subaddress within the register map. The read and write procedures for the HDMI receiver are depicted in Figure 3[4]. The HDMI transmitter is programmed via I²C in the same manner with different register maps.

6


Figure 3: I²C read and write sequence and bus data signaling. An ACK is indicated by pulling the SDATA line low and a NACK is indicated by pulling the SDATA line high.

### 4.4 PCB Integration

To integrate the HDMI interfaces with the DE2-115 the HDMI chips must be housed on a PCB to interface with small chip package. Each HDMI interface PCB will connect to the DE2-115 through a GPIO header on the HSMC to GPIO daughter board. Eagle schematics for the HDMI receiver PCB are located in hdmi receiver.sch. Care was taken to include several termination resistors and decoupling capacitors in order to maintain the interface system stability. A 3-layer PCB was design with an internal GND plane and percautions were taken to keep the HDMI differential signals parallel and similar in length. The HDMI transmitter PCBs will have a similar design to the HDMI receiver PCB. Having separate PCB designs for the transmitter and receivers provides individual control over each interface and may simplify component upkeep with separated designs.

7

### 4.5 Block Diagram


Figure 4: HVD systems block diagram

## 5 Results

### 5.1 Timeline

The past development cycle for the HVD is illustrated in the timeline in Figure 5.


Figure 5: Development timeline

8

### 5.2 HDMI Receive Interface

This development cycle focused on the HDMI receive interface implementation including the PCB design, testing, and DE2-115 I²C communication. The receiver was developed first in order to avoid unnecessary development requirements to test the HDMI interface. Ideally to test the HDMI transmit functionality we would ultimately want to transmit a video frame. Instead of having the FPGA generate a video frame, establish a the receiver to acquire a frame instead for later output reduced the software development.

The eagle design files for the HDMI receiver PCB are hdmi receiver.sch and hdmi receiver.brd. This prototype serve as a sufficient test board for identifying early design errors. One such error was already discovered; the footprint for the DC power jack is incorrect making the barrel receptacle impossible to solder to the board without modifications. Further testing is required to verify the functionality of this board which wasn’t achieved during this development cycle.

### 5.3 I²C Protocol

The I²C protocol is essential for controlling the HDMI receive interface using the DE2-115. The I²C module was implemented in Verilog and tested through several mediums. First, Alter’a ModelSim IDE was used to verify the module could be instantiated and successfully produce the desired waveforms in simulation. The real signal generation of the module was observed and checked using oscilloscopes. Some oscilloscope waveform samples are shown and described in Figures 6 and 7. This also verified that the pin configurations over the HSMC to GPIO daughter board were correct and functional. Finally, Link Instruments MSO-19.2 with a built in I²C protocol interpreter was used to confirm the I²C module signals were successfully interpreted to comply to the I²C standard.

9


Figure 6: Screen captured from oscilloscope reading I²C data. The top signal is the SDA and the bottom is SCL.A write sequence is depicted in the captured image. First the SDA is pulled low while the SCL signal is high to indicate a START condition. This enable the generated of the I²C serial clock signal which SCL is connected to. The first data transmitted across the SDA line is the slave address, which in this case is 0x1 in 7-bits. After the 7th bit is transmitted the R/W bit which is zero for a write sequence is sent. On 9th the SCL clock pulse, the SDA line is set to high impedance to acquire an acknowledge input from the slave device. In this case, there is no slave device connected so the SDA remains unchanged. Afterward the subaddress 0x4 is sent in 8-bits in the same fashion.

10


Figure 7: Screen captured from oscilloscope reading I²C data. The top signal is the SDA and the bottom is SCL.A read sequence is depicted in the captured image. Before a read transaction, the subaddress pointer must be set by a previous write transaction. First the SDA is pulled low while the SCL signal is high to indicate a START condition. The first data transmitted across the SDA line is the slave address, which in this case is 0x1 in 7-bits. After the 7th bit is transmitted the R/W bit which is one for a read sequence is sent. ON the 9th SCL clock pulse, the SDA line is set to high impedance to acquire an acknowledge input from the slave deivce. In this case, there is no slave device connected so the SDA remains mostly unchanged. Afterwards the SDA remains set to high impedance to accept input on the SDA line. The SDA line is then only controlled by the master when asserting an ACK or NACK. This signal receives no input but because the SDA line is left at high impedance there is a noticeable decay in the signal.

The simulation and oscilloscope tests and check were successful but the test data offered by the MSO-19.2 gave questionable data that didn’t completely confirm our I²C module conformity to the standard protocol. A lack of explicit documentation on the data presented by the I²C interpreter user interface, incorrect signal timing values, and some unexpected protocol behavior makes it so the test in not a perfect verification of the I²C protocol correctness. A sample of MSO-19.2 data is shown and described in Figure 8.

11


Figure 8: This is MSO data from an I²C write sequence. Channel 4 is the SCL signal and Channel 5 is the SDA signal. The I²C interpreted data is shown in a console window to the right. Start and Stop condition are detected successfully. The data bytes represented in the console window are also correct. However the timing units in microseconds are for some reason off by a factor of 10. Each clock cycle should take approximately 2.5 microseconds while the MSO data shows approximately 25 microseconds. There also is a matter concerning the NACK. The MSO interpeter should generate acknowledge signal for valid I²C data but after receiving a 0xB data byte in this case it generated a NACK. The cause for this is unknown.

## 6 Analysis

### 6.1 Testing

The HDMI receiver PCB and I²C protocol tests are largely incomplete. The goal for integrated these two systems was also not achieved. Some lack of development foresight in development time led to delays and deviation from the original time line became inevitable. Since the I²C protocol correctness isn’t completely verified, we will have to examine if its current implementation is able to properly communicate with the HDMI receive PCB. Examining the functionality of the PCB, ADV7611 HDMI receiver, and the correctness of the I²C protocol at the same time can lead to difficult debugging scenarios involving multiple variables. Unless more investment is made to further test the I²C protocol with additional testing hardware, the cluttered testing

12 scenario may be inevitable.

### 6.2 Development Time

Setbacks in the initial development cycle will propagate through to the next. Expected project goals must be re-evaluated. It is an end design goal to be able to process and divide a single HDMI signal into two separate signals. In order to fully implement the hardware and integrate the system, time to development image processing requirements may be sacrificed. The image processing logic, while it is an essential part of the HVD’s ideal application, must be the first feature to be dropped from expected implementations in the next development cycle because it reliant on functioning hardware and complete system integration. A proposed time line for next development cycle is shown in Figure 9. Notice that there is no time reserved for the image processing algorithms necessary for the HVD goal application.


Figure 9: Next cycle development timeline

13

### 6.3 Budget

The cost reports for this development cycle was rather high. The PCB fabrication expense for HDMI receiver consumed most of the allowed budget. In order to improve the HVD cost efficiency, future versions should be reduced from a 3-layer to 2-layer board. This will present more design constraints in order to ensure signal integrity. Examining current design faults in the HDMI receive PCB will lend insight when designing the HDMI transmit PCB.

## 7 Conclusion

Results of this development cycle are less than optimal. Several pivitol tasks and goals that were not completely satisfied and others were pushed back resulting. However, steady though unideal progress on the development of the HVD systems has deviated little from the original implementation designs. We are confident that the design plans for the HVD remains sound.

Overall, the major systems that were suppose to be complete within this cycle still need to be verified and tested. Once all the issues are determined, they can be addressed in future design iterations. While development on the HDMI transmit interface was never achieved, it’s similarity to the HDMI receive interface means and problems encountered in devloping the receiver can be avoided when designing the transmitter. The I²C protocol module on the DE2-115 will also function in communication with the transmitter.

In the following cycle, once the previous tasks are completed. A quick rework of the receiver PCB, prototype of the transmitter PCB and I²C integration should be achievable. The remaining time can be spent working on the HDMI configuration software and memory logic on the Cyclone IV. The image processing development has been delayed, but focus on the HVD hardware and interface systems is an absolute priority.

14

## 8 Acknowledgements

We would like to acknowledge the following persons, whose contributions and guidance made the development and execution of this project possible.

Lukas van Ginneken for instructing and assisting in planning the project, identifying design constraints, and providing development solutions. Jeremy Thomas for instructing, offering guidance on engineering practices, and encouragement that helped keep us motivated. Christopher Theriault for managing the project budget, acquiring necessary resources, and providing test tools. Nicholas Rivera for sharing his experience and knowledge in embedded systems designs. And Johnny Sim for sharing his experience and knowledge of Altera’s FPGA development software.

Thank you for all of your support.

## References

[1] Altera, www.Altera.com, Video and Image Processing Design Using FP-GAs.
[2] Analog Devices, www.Analog.com, Low Power 165 MHz HDMI Receiver, 2010-2012.
[3] Analog Devices, www.Analog.com, 165 MHz, High Performance HDMI Transmitter.
[4] Analog Devices, www.Analog.com, ADV7611 Reference Manual, 2010-2014.
[5] Analog Devices, www.Analog.com, ADV7513 Hardware User’s Guide rev. 0, November 2011.
[6] www.hdmi.org, “Introducing hdmi 2.0.” Web, Dec. 2014.
[7] Terasic and Altera, www.terasic.com, DE2-115 User Manual.
[8] Altera, www.altera.com, Cyclone IV Device Handbook Vol 1, November, 2011.
[9] Hitachi, Ltd. and Matsushita Electric Industrial Co., Ltd. and Philips Consumer Electronics, International B.V. and Silicon Image, Inc. and Sony Corporation and Thomson Inc. and Toshiba Corporation,

15 www.microprocessor.org, High-Definition Multimedia Interface Specification Version 1.3a, November 10, 2006.

[10] Terasic, www.terasic.org, THDB-HTG Terasic HSTC to GPIO Daughter Board, Dec 23, 2008.

16

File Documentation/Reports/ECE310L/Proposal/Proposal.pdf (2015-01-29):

# HDMI Divider

### Cassandra Chow

### September 18, 2014

Abstract

With the detailed project we will strive to design an embedded system that will

enable the user to divide a primary high-definition multimedia interface (HDMI) display

source into two separate outputs that each display half of the primary display. The

application of this device if focused at enabling video game players to assign parts

of the game display to other dedicated displays which can be useful for multiplayer

games designed with split-screen gameplay. To do this, our product will need to accept

HDMI input frames, divide that input into two separate output frames, and process

the output frame to suit their individual displays.

1

## Contents

1 Introduction | 3
2 Methods, Techniques, and Design | 5
3 Parts List | 8
4 Timeline | 8
5 Citation | 10

2

## 1 Introduction

Our product, which we will call an HDMI Divider for now, will be designed to give its user

a solution to dividing split-screens that is not otherwise offered by the application or display

hardware itself. The application of the HDMI splitter is illustrated in Figure 1. Because

the HDMI divider will be able to accept HDMI signals from an arbitrary source device, it’s

application can be utilized across any platform using HDMI output. Giving consumers the

option of dividing their display can enhance the experience of video game players especially

in competitive gameplay. Where players are competing, it is in the best interest of each

user to win against the other in some manner but a split-screen setup prevents the players

from concealing their actions from the other. Another reason players might find this device

attractive is just the ability to expand their split portion of the screen to a larger display.

3


Figure 1: Represents use model concept of the HDMI divider dividing a split-screen into two

dedicated displays

This project also acts as a challenging learning experience to an undergraduate student.

Since we will be utilizing the digital logic on a field-programmable gate array (FPGA) to

accomplish our device implementation, we will not only become more familiar with FPGA

applications but also obtain a better grasp on embedded system architecture and the HDMI

protocol specification. Most projects of interest to us required in-depth knowledge in proto-

cols that are widely used in various electronics, therefore a project which includes develop-

4

ment on the HDMI is the main reason for undertaking this task. All of the above benefits

will be sought out in order to improve our design capabilities as an engineer.

## 2 Methods, Techniques, and Design

### 2.1 Design Considerations

To understand the requirements for our project we must examine our resource requirments

which includes knowing what data we are acquiring, how the data is being acquired, and

what our device will do with that data. For our application model we will require the dis-

play data from some external source which will be transmitted via the HDMI interface. The

received display data must be processed and then output across two individual displays.

Our target display format is the standard HDTV configuration which supports a resolution

of 1920x1080p. The platform we decided on to implement our design is an FPGA. FPGAs

are known for being able to perform signal processing quickly which is critical in display

applications. The specific development platform we will be using is Altera’s DE2-115 Devel-

opment and Education board.The DE2 provides us with sufficient means in accomplishing

our project requirements while also being flexible to future changes.

### 2.2 HDMI Display

According to the HDMI specification, there are three data channels used to transmit pixel

data typically at a resolution of 24 bits per pixel, 8 bits per channel. The HDMI interface

5

has a pixel clock that functions at a maximum of 165 MHz [3]. The DE2 can support

the necessary switching speed on it’s I/O lines but the on-board SRAM and SDRAM have

insufficient bandwidth capabilities to store the data fast enough. We will therefore be writing

to the embedded memory on the FPGA chip allowing us to take advantage of the speed

capabilities on the FPGA. There are only 486 Kbytes of embedded memory on the Cyclone

IV DE2 FPGA chip [1], so we cannot store entire frames but this is sufficient space to store

the each line of data for each input and output frame until it it is processed. Then by using

a simple image rescaling algorithm, such as nearest neighbor or interpolation, we can als

ensure we are able to resize the image properly even if we cannot send and receive an entire

frame at once.

There is no onboard solution for implementing the HDMI protocol on the DE2 board,

therefore we will being using HDMI transmitter and HDMI receiver chipsets. Each selected

chipset requires approximately 32 I/O lines [2] to interface with the DE2 but the DE2 board

only has 36 GPIO pins mapped to the the Cyclone IV [6]. However, we can expand the

number of GPIO pins available by connection an expansion board to the DE2’s High-Speed

Mezzanine Connector (HSMC), giving us access to another three GPIO headers. Since we

only need 3 HDMI interface, 1 input and 2 outputs, we will only have enough GPIO pins

available if we use the HSMC GPIO expansion daughter card. To implement the HDMI

chipsets and connection, we’ll be designing a PCB for each to interface with the DE2 though

the GPIO expansion. Our implementation for our device is illustrated by the system block

diagram in Figure 2.

6

### 2.3 System Block Diagram


Figure 2: Block Diagram of device implementation

7

## 3 Parts List

These are the primary components required for our HDMI Divider implementation

- Altera DE2-115 Education and Development Board [6]
- THDB-HTG GPIO daughter board [5]
- ADV7611 HDMI Receiver [2]
- AD9389B HDMI Transmitter x2 [4]

## 4 Timeline

Figure 3 is the task timeline we have set for ourselves over the next 12 weeks of de-

velopment. By the end of 12 weeks we should be able to confirm HDMI input and output

functionality including the memory architecture requirements. Notice that we are not going

to be working on the image processing required for dividing and resizing the display output

yet, just establishing the protocol functionality on the FPGA.


Figure 3: Timeline for development tasks

8

PLL Clock Generation Configuring the PLL on the FPGA to generate desired clock rates

for processing

HDMI Input PCB Design Designing the PCB for the daughter card implementing the

HDMI input port and interface

HDMI Output PCB Design Designing the PCB for the daughter card implementing the

HDMI output port and interface

Embedded Memory Test Bench Configuring embedded memory system and testing read/write

functionality

HSMC Signal Test Bench Configuring signal I/O over the HSMC to GPIO bus and test-

ing functionality

HDMI Input Firmware Developing FPGA digital logic for receiving HDMI display data

HDMI Output Firmware Developing FPGA digital logic for transmitting HDMI display

data

Pixel Data Read/Write Developing the read/write process for storing display data in

memory

Final Report Compiling final project results into a report document

Presentation Preparing and delivering presentation of project results

9

## 5 Citation

## References

[1] Altera. Cyclone IV Device Handbook Vol 1, November, 2011.
[2] Analog Devices. Low Power 165 MHz HDMI Receiver, 2010 - 2012.
[3] Ltd. Hitachi, Ltd. Matsushita Electric Industrial Co., International B.V. Philips Con-

sumer Electronics, Inc. Silicon Image, Sony Corporation, Thomson Inc., and Toshiba

Corporation. High-Definition Multimedia Interface Specification Version 1.3a, Novem-

ber 10, 2006.

[4] Terasic. High Performance HDMI/DVI Transmitter, 2007.
[5] Terasic. THDB-HTG Terasic HSTC to GPIO Daughter Board, Dec 23, 2008.
[6] Terasic and Altera. DE2-115 User Manual.

10

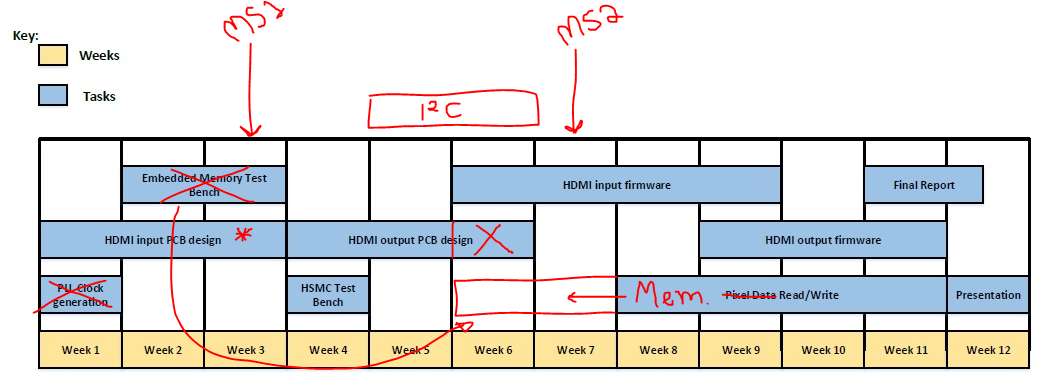
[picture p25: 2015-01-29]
Documentation/Reports/ECE310L/Milestone 1/Timeline_edit.PNG

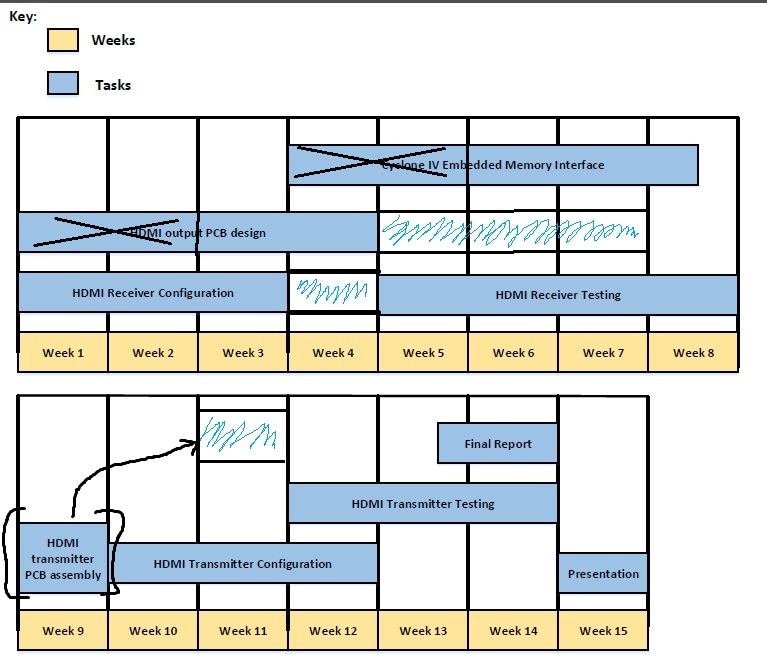
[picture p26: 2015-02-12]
Documentation/Presentations/ECE460L/Milestone1/timeline_spring_m1.jpg

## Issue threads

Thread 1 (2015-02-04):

I²C Repeating Start

chow004, 2015-02-04:
Implementation of repeating start is incorrect. Currently it tries to keep the clock HIGH during the final acknowledge (ACK is LOW) which is incorrect according to the specification. Fix and test in simulation and oscilloscope.

chow004, 2015-02-11:
FIXED. Repeating start occurs after the ACK clock cycle is fully completed. This was tested in the read sequences on the I²C bus which were successful.

Closed 2015-02-11.

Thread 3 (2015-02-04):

I²C Read

chow004, 2015-02-04:
Current write requests to the ADV7611 device appear to be acknowledged successfully despite some incorrect protocol specifications. During a read request the slave device fails to take control of the SDA line. The slave device should be allowed to control the SCL line at this time as well.

chow004, 2015-02-11:
FIXED. I²C reads now successfully acquires the register contents of specified subaddress from IO register map. The problem likely resulted in a incorrect repeating start and incorrect stop signal. I assumed that the stop or repeated start occurred immediately after the ACKnowledge so I was stopping the SCL clock early. The slave device also does not need to control the SCL line, the clock-stretching referred to in the specification is likely a special case that may happen.

Closed 2015-02-11.

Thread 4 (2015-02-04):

Receiver PCB ver 1.0 Bad Power Jack Footprint

chow004, 2015-02-04:
The footprint for the barrel power jack has its switch pin on the wrong side. Since we aren't using the switch functionality we worked around this by cutting that pin off of the part. Next PCB versions, however, should amend this.

chow004, 2015-03-17:
Until another version of the PCB is developed this will be marked as wontfix.

Closed 2015-03-17.

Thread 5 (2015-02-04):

Receiver PCB ver 1.0 Switch De-bouncing

chow004, 2015-02-04:
Capacitors should be added close to the reset switch circuit for de-bouncing.

chow004, 2015-03-17:
Until another version of the PCB is developed this will be marked as wontfix

Closed 2015-03-17.

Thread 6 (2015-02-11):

I²C Continuous Read/Write Broken

chow004, 2015-02-11:
When continuously reading or writing on the I²C bus, the data is interpreted incorrectly. This error is purely interpretation because the data is still consistent. For example, when we expect to read a 0x06 in a register we get either a 0x19 or 0x03. The waveform on the oscilloscope corresponds with this incorrect information. Thus we suspect that when repeated reading from the IO map, we may be trying to query data from the chip too fast or we are not resetting the state machine correctly before it changes to another read/write sequence in time. A temporary work around is to make sure we only perform one read/write and then must physically push a button to reset the SM before we can do another read/write. This works and the I²C data is correct. To fix we need to either fix the SM reset or if that doesn't work, add a delay between each read/write.

chow004, 2015-03-17:
Added a I2C_READY flag that ensure the bus state machine must maintain at least 1 serial clock cycle in the IDLE state between transactions. Also added a 'busy' flag in order to indicate when the bus is currently busy with a transaction. The main program should not attempt to change the contents of the transmit or receive registers when the I²C is busy.

Closed 2015-03-17.

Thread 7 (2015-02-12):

HDMI PCB ESD protection

chow004, 2015-02-12:
In the hardware user manual for the ADV7513 HDMI transmitter, it recommends a ESD protection circuit between the IO of the ADV7513 and the HDMI connector. The hardware user guide for the ADV7611 HDMI receiver does not mention a need for an ESD protection circuit but apparently many consumer electronics manufacturers require the HDMI port to be "ESD hardened," often according to the IEC6100-4-2 ESD standard. Other resources state that for HDMI Hot-Plug capability ESD is required. When designing the transmitter PCB I add an ESD protection circuit as suggested and also consider adding it to the revamped receiver PCB after more research.

chow004, 2015-03-31:
The ADV7513 development is on hold now, so this will be marked as 'wont fix' until further notice

Closed 2015-03-31.

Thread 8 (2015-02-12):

HDMI PCB Transmitter ver 1.0 - No Audio Pins

chow004, 2015-02-12:
While drafting the schematic for the ADV7513 HDMI transmitter we found that there was insufficient space for the necessary audio outputs (I²S, MCLK, LRCLK, SCLK). To route these signals to the GPIO header we would need at least 6 more pins. Since audio capability isn't part of our design goals, the feature will have to be cut completely, leaving no potential for audio capabilities later on the same PCB.   Perhaps audio can be added later if a ASIC design is fabricated from the FPGA and implemented on its own PCB.

chow004, 2015-02-12:
However, adding breakout pads on the PCB wouldn't hurt. If it doesn't degrade signal integrity too severely, there is a chance we can wire-mess the audio inputs to another available header.

Closed 2015-03-17.

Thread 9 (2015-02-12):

I²C Work only with O-scope probes attached

chow004, 2015-02-12:
Currently the I²C protocol is only functioning correctly if oscilloscope probes are attached. This is because oscilloscope probes add a large resistance and small capacitance to the nodes they are attached, reducing the effective impedance by a small amount. Therefore if we decrease the impedance in our circuit it should function correctly. Several methods should be investigated and tested for doing this. (i.e. changing the bus capacitance or resistance, or reducing the I²C protocol speed)

chow004, 2015-02-19:
FIXED. The exact reason why this was an issue is still unclear. Adding capacitance of 47pF, 100pF, or 220 pF to the lines did not fix the issue even though http://www.i2c-bus.org/ recommends that high capacitance for compensating low resistance. The pull-up resistance on the I²C lines is 1.5k ohms.

As per Christopher Theriault's suggestion I decided to remove the on-board 50pF capacitors to lower the capacitance. The I²C bus seemed to function correctly without the probes after removing the capacitors, however when I added 47pF or 100pF after this removal it also functioned even though I effectively increased the capacitance beyond the on-board capacitance.

For now we know that removing the 50pF will allow the I²C to function properly, but since the exact nature of this fix doesn't seem consistent, we may keep an eye out for this behavior resurfacing.

Closed 2015-02-19.

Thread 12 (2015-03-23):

PC to ADV7611 Communication

chow004, 2015-03-23:
Currently their are several problems regarding the PC to daughter board HDMI communication. First the PC does not detect a valid display device over HDMI which could be because of several reasons:
1.) Hot Plug Detect pin is not being asserted
2.) Settings Issue (Use Recommended Settings from Analog Devices)
3.) Invalid EDID block in EDID memory (Extended Display Identification Data)

chow004, 2015-03-23:
I have already resolved possible issues surrounding the hot plug pin. The hot plug pin HPA_A must have a 1k pull-up resistor to RXA_5V. Since this wasn't mentioned in the PCB layout section I neglected to do this. I've managed to add the aforementioned pull-up to the board and confirmed it is pulling up when the HDMI cable from the PC is connected.

However, I am not following all the recommended settings or writing a EDID block to EDID memory. The EDID is used to describe display capabilities to the video source, the PC graphics card, so it is likely this is invalid and preventing the PC from detecting a proper HDMI display.

chow004, 2015-03-25:
Note: many ADI (Analog Devices Inc.) required register assignments are not specified in the hardware user guide or the software manual. A solid documentation source on what these ADI registers is not available but seems essential to the stability of the HDMI receiver. Since their are numerous registers, need to implement some initial RAM memory for writing initialization data over I²C.

chow004, 2015-03-31:
By adhering to sample scripts provided by ADI for register setup and EDID blocks, I was able to successfully initialize the ADV7611 so that is appropriately detected by an HDMI source(PC). Currently the PC detects the device as a third and outputs a recommended 1080i. This can be changed to 1080p in the resolution setting.

Closed 2015-03-31.

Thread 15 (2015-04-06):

ADV7611/DE2-115 Initialization Unstable

chow004, 2015-04-06:
There is a issue when initially programming the DE2-115 and sending initial I²C transfers. The ADV7611 main I²C seems to get stuck outputting 0x7F and doesn't respond to I²C writes either. If I reset the ADV7611 only (not the DE2-115) then the I²C returns to normal functionality but this is an issue since I'm trying to do a lot of initial I²C writes on startup. Now I have to add a switch logic to resend initialization data manually which then works fine. Perhaps adding a short delay on start up might fix the problem by ensuring all logic is initialized correctly.

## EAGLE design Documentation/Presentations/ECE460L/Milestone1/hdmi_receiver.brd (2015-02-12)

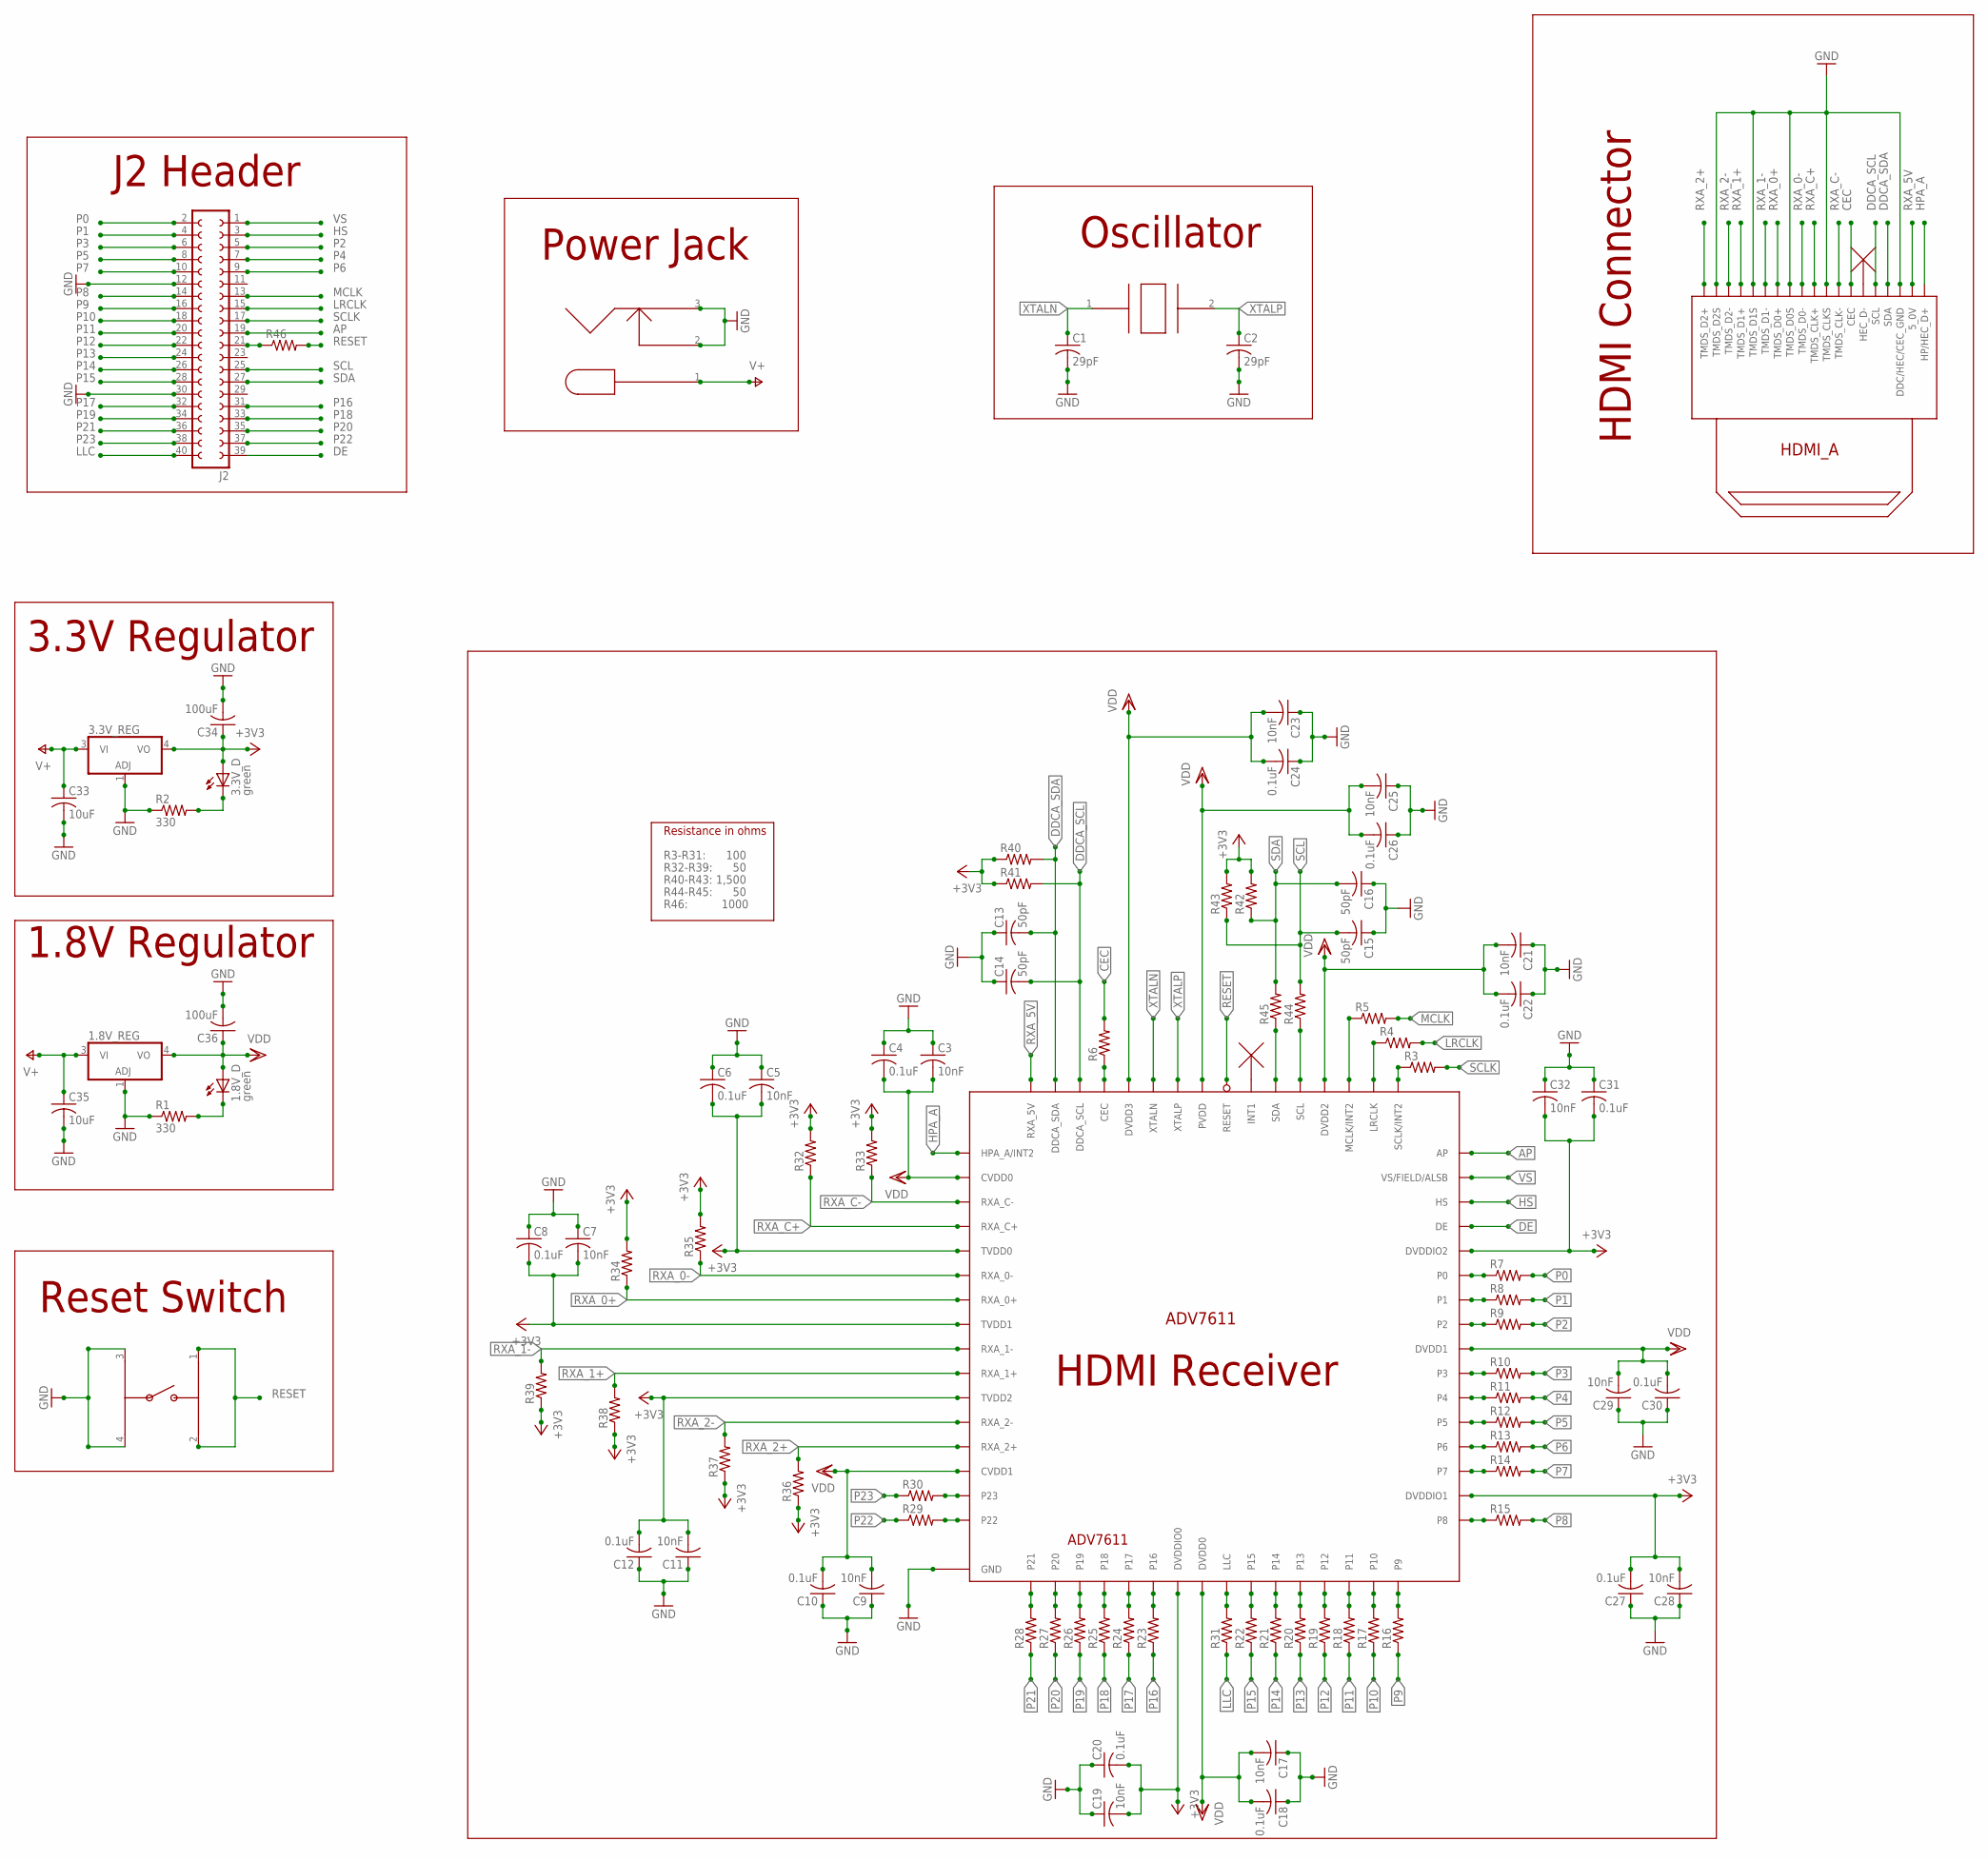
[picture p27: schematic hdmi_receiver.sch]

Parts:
1.8V_D, 3.3V_D: green; LED5MM
1.8V_REG, 3.3V_REG: 317EMP; SOT223
ADV7611: ADV7611; LQFP-ST-64-2
C1, C2: 29pF; C1210
C3, C5, C7, C9, C11, C17, C19, C21, C23, C25, C28, C29, C32: 10nF; C0603
C4, C6, C8, C10, C12, C18, C20, C22, C24, C26, C27, C30, C31: 0.1uF; C0603
C13, C14, C15, C16: 50pF; C0603
C33, C35: 10uF; C0603
C34, C36: 100uF; C1206
J2: FE20-2
R1, R2: 330; R0603
R3, R4, R5, R6, R7, R8, R9, R10, R11, R12, R13, R14, R15, R16, R17, R18, R19, R20, R21, R22, R23, R24, R25, R26, R27, R28, R29, R30, R31, R32, R33, R34, R35, R36, R37, R38, R39, R40, R41, R42, R43, R44, R45, R46: R-US_R0603; R0603
U$1: 111RLF
U$2: CRYSTAL_OSC
U$3: CK_SWITCH
U$4: DC_BARREL_CONN

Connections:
+3V3: 3.3V_D.A, 3.3V_REG.4 (VO), ADV7611.5 (TVDD0), ADV7611.8 (TVDD1), ADV7611.11 (TVDD2), ADV7611.23 (DVDDIO0), ADV7611.34 (DVDDIO1), ADV7611.44 (DVDDIO2), C5.2, C6.2, C7.2, C8.2, C11.2, C12.2, C19.2, C20.2, C27.2, C28.2, C31.2, C32.2, C34.1, R32.2, R33.2, R34.2, R35.2, R36.1, R37.1, R38.1, R39.1, R40.1, R41.1, R42.2, R43.2
AP: ADV7611.48 (AP), J2.19
CEC: R6.2, U$1.13 (CEC)
DDCA_SCL: ADV7611.62 (DDCA_SCL), C14.2, R41.2, U$1.15 (SCL)
DDCA_SDA: ADV7611.63 (DDCA_SDA), C13.2, R40.2, U$1.16 (SDA)
DE: ADV7611.45 (DE), J2.39
GND: 1.8V_REG.1 (ADJ), 3.3V_REG.1 (ADJ), ADV7611.0 (GND), C1.2, C2.2, C3.1, C4.1, C5.1, C6.1, C7.1, C8.1, C9.1, C10.1, C11.1, C12.1, C13.1, C14.1, C15.1, C16.1, C17.1, C18.1, C19.1, C20.1, C21.1, C22.1, C23.1, C24.1, C25.1, C26.1, C27.1, C28.1, C29.1, C30.1, C31.1, C32.1, C33.2, C34.2, C35.2, C36.2, J2.12, J2.30, R1.1, R2.1, U$1.2 (TMDS_D2S), U$1.5 (TMDS_D1S), U$1.8 (TMDS_D0S), U$1.11 (TMDS_CLKS), U$1.17 (DDC/HEC/CEC_GND), U$3.3, U$3.4, U$4.2, U$4.3
HPA_A: ADV7611.1 (HPA_A/INT2), U$1.19 (HP/HEC_D+)
HS: ADV7611.46 (HS), J2.3
LLC: J2.40, R31.1
LRCLK: J2.15, R4.2
MCLK: J2.13, R5.2
unnamed: ADV7611.25 (LLC), R31.2
unnamed: 1.8V_D.K (C), R1.2
unnamed: 3.3V_D.K (C), R2.2
unnamed: ADV7611.49 (SCLK/INT2), R3.1
unnamed: ADV7611.50 (LRCLK), R4.1
unnamed: ADV7611.51 (MCLK/INT2), R5.1
unnamed: ADV7611.61 (CEC), R6.1
unnamed: ADV7611.39 (P3), R10.1
unnamed: ADV7611.38 (P4), R11.1
unnamed: ADV7611.37 (P5), R12.1
unnamed: ADV7611.36 (P6), R13.1
unnamed: ADV7611.35 (P7), R14.1
unnamed: ADV7611.54 (SDA), R45.1
unnamed: ADV7611.53 (SCL), R44.1
unnamed: J2.21, R46.1
unnamed: ADV7611.32 (P9), R16.2
unnamed: ADV7611.31 (P10), R17.2
unnamed: ADV7611.30 (P11), R18.2
unnamed: ADV7611.29 (P12), R19.2
unnamed: ADV7611.28 (P13), R20.2
unnamed: ADV7611.27 (P14), R21.2
unnamed: ADV7611.26 (P15), R22.2
unnamed: ADV7611.22 (P16), R23.2
unnamed: ADV7611.21 (P17), R24.2
unnamed: ADV7611.20 (P18), R25.2
unnamed: ADV7611.19, R26.2
unnamed: ADV7611.18 (P20), R27.2
unnamed: ADV7611.17 (P21), R28.2
unnamed: ADV7611.16 (P22), R29.2
unnamed: ADV7611.15 (P23), R30.2
unnamed: ADV7611.33 (P8), R15.1
unnamed: ADV7611.41 (P2), R9.1
unnamed: ADV7611.42 (P1), R8.1
unnamed: ADV7611.43 (P0), R7.1
P0: J2.2, R7.2
P1: J2.4, R8.2
P2: J2.5, R9.2
P3: J2.6, R10.2
P4: J2.7, R11.2
P5: J2.8, R12.2
P6: J2.9, R13.2
P7: J2.10, R14.2
P8: J2.14, R15.2
P9: J2.16, R16.1
P10: J2.18, R17.1
P11: J2.20, R18.1
P12: J2.22, R19.1
P13: J2.24, R20.1
P14: J2.26, R21.1
P15: J2.28, R22.1
P16: J2.31, R23.1
P17: J2.32, R24.1
P18: J2.33, R25.1
P19: J2.34, R26.1
P20: J2.35, R27.1
P21: J2.36, R28.1
P22: J2.37, R29.1
P23: J2.38, R30.1
RESET: ADV7611.56 (RESET), R46.2, U$3.1, U$3.2
RXA_0+: ADV7611.7 (RXA_0+), R34.1, U$1.7 (TMDS_D0+)
RXA_0-: ADV7611.6 (RXA_0-), R35.1, U$1.9 (TMDS_D0-)
RXA_1+: ADV7611.10 (RXA_1+), R38.2, U$1.4 (TMDS_D1+)
RXA_1-: ADV7611.9 (RXA_1-), R39.2, U$1.6 (TMDS_D1-)
RXA_2+: ADV7611.13 (RXA_2+), R36.2, U$1.1 (TMDS_D2+)
RXA_2-: ADV7611.12 (RXA_2-), R37.2, U$1.3 (TMDS_D2-)
RXA_5V: ADV7611.64 (RXA_5V), U$1.18 (5_0V)
RXA_C+: ADV7611.4 (RXA_C+), R32.1, U$1.10 (TMDS_CLK+)
RXA_C-: ADV7611.3 (RXA_C-), R33.1, U$1.12 (TMDS_CLK-)
SCL: C15.2, J2.25, R43.1, R44.2
SCLK: J2.17, R3.2
SDA: C16.2, J2.27, R42.1, R45.2
V+: 1.8V_REG.3 (VI), 3.3V_REG.3 (VI), C33.1, C35.1, U$4.1
VDD: 1.8V_D.A, 1.8V_REG.4 (VO), ADV7611.2 (CVDD0), ADV7611.14 (CVDD1), ADV7611.24 (DVDD0), ADV7611.40 (DVDD1), ADV7611.52 (DVDD2), ADV7611.57 (PVDD), ADV7611.60 (DVDD3), C3.2, C4.2, C9.2, C10.2, C17.2, C18.2, C21.2, C22.2, C23.2, C24.2, C25.2, C26.2, C29.2, C30.2, C36.1
VS: ADV7611.47 (VS/FIELD/ALSB), J2.1
XTALN: ADV7611.59 (XTALN), C1.1, U$2.1
XTALP: ADV7611.58 (XTALP), C2.1, U$2.2

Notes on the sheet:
R3-R31: 100
Resistance in ohms
R32-R39: 50
R40-R43: 1,500
R44-R45: 50
R46: 1000
RESET
HDMI Receiver
J2 Header
Power Jack
Oscillator
HDMI Connector
3.3V Regulator
1.8V Regulator
Reset Switch
ADV7611

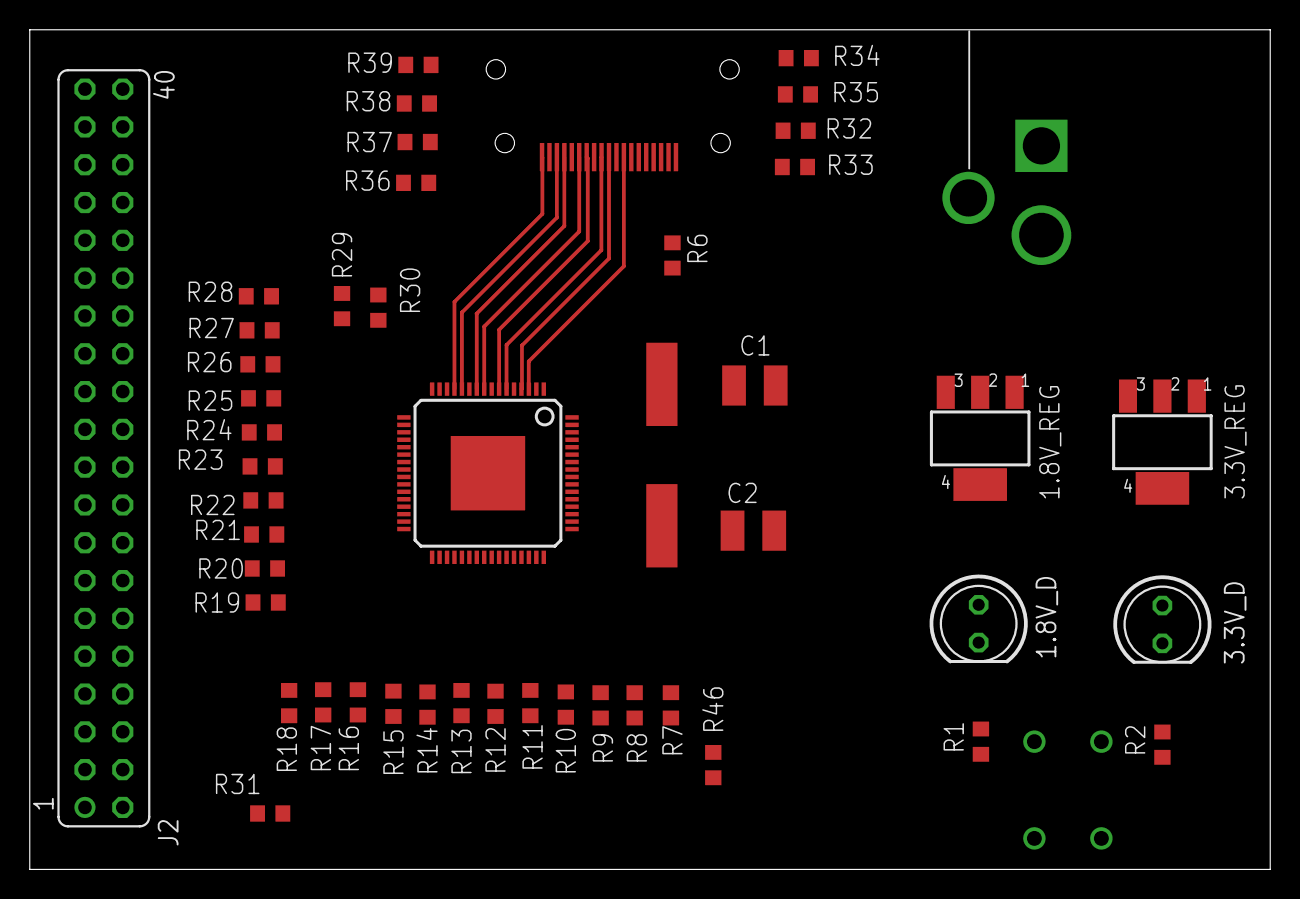
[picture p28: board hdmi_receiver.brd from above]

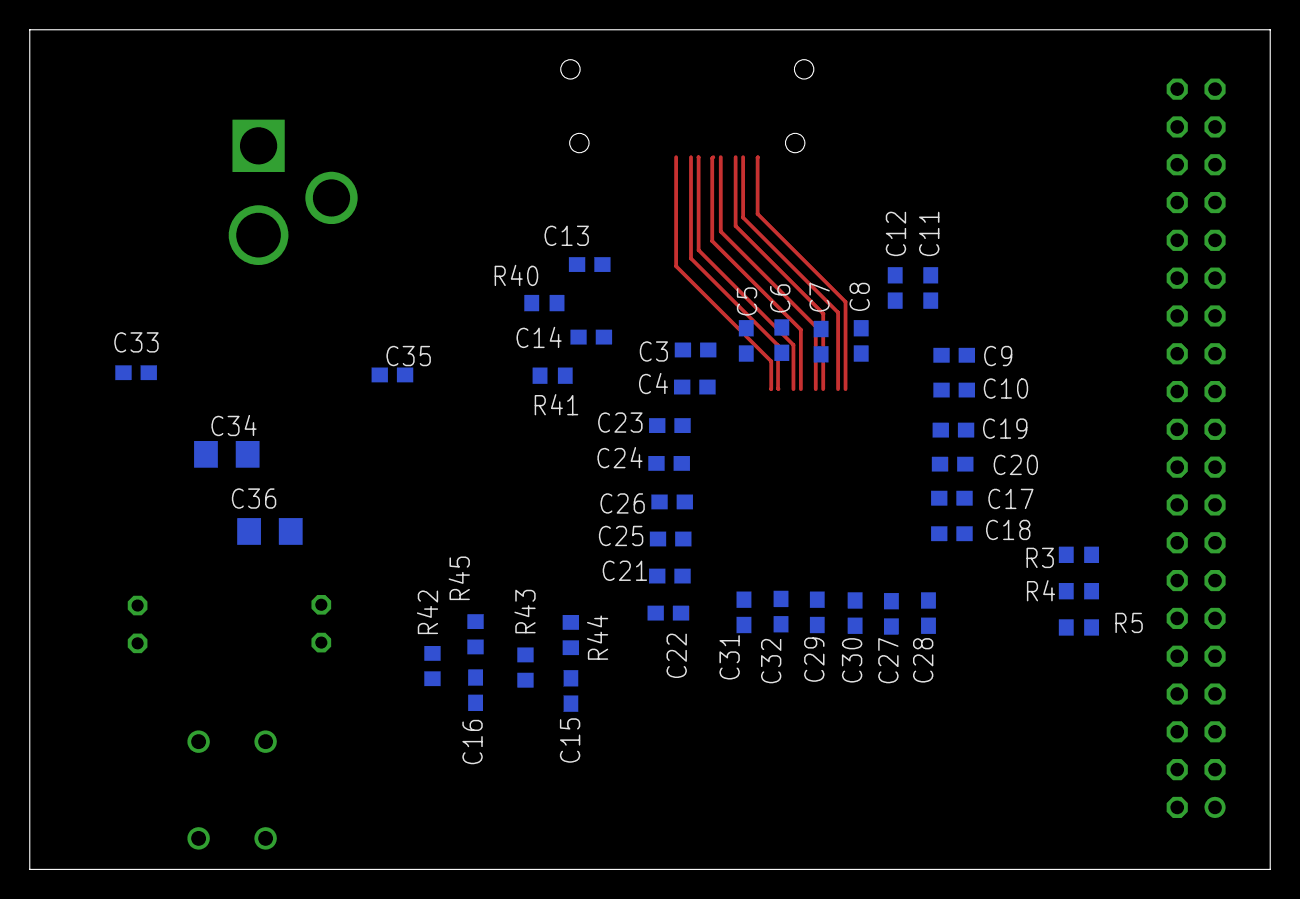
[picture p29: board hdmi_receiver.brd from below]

Board: 2 copper layers, 83.3 x 56.4 mm, 92 parts (43 on the bottom side), 88 nets.

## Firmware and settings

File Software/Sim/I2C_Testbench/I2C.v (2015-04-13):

/*==========================================================
	File: I2C.v
	Author: Cassandra Chow
	Copyright DigiPen Institute of Technology 2014
	Brief: Module for implementing i2c protocol targeted
			 for the Altera DE2-115 Dev. Board
==========================================================*/
module I2C(
clk_50,
WR,
length,
request, 
DE,
SDA, 
SCL, 
txReg, 
rxReg, 
address, 
sub_address, 
busy,
scl_ticks);
				
input			   clk_50;
input			   WR;
input			   [7:0]length;
input			   request;

input			   [6:0]address;
input			   [7:0]sub_address;

input			   [7:0]txReg;		// transmit register
output reg	[7:0]rxReg;		// receive register

inout			      SDA;
inout 		      SCL;
output reg	   DE;			// data enable
									// ... indicates when register has processed 1 byte
									
output reg	busy;

// state variables
reg [1:0]State;
reg	[1:0]subState;
reg	[1:0]Next;
reg	[1:0]subNext;

// states
parameter 	IDLE 		= 2'b00;
parameter 	SETUP 	= 2'b11;
parameter 	READ		= 2'b10;
parameter 	WRITE		= 2'b01;
// substates
parameter	ssADDR		= 2'b00;
parameter	ssSADDR		= 2'b01;
parameter	ssRECEIVE	= 2'b10;
parameter	ssIDLE		= 2'b11;

// clock control variables
reg			[6:0]counter;
reg   counter_reset;

// data control variables
reg			[7:0]bytes_processed;
output reg			[3:0]scl_ticks;
reg		 I2C_DATA;
reg 		I2C_CLK;

// system clocks
reg			CE;
reg			LCLK;

// bus lines are open-drain
assign SDA = ~I2C_DATA ? 0 : 1'bZ;
assign SCL = ~I2C_CLK ? 0 : 1'bZ;

initial begin
	rxReg = 0;
	DE = 0;
	
	State = IDLE;
	subState = ssADDR;
	Next = IDLE;
	subNext = ssADDR;
	
	LCLK = 0;
	CE = 0;
	counter = 0;
	counter_reset = 0;
	
	I2C_CLK = 1;
	I2C_DATA = 1;
	bytes_processed = 0;
	
	scl_ticks = 0;
	busy = 0;
end

// 7-bit counter -> 390.625 kHz
always @ (posedge clk_50) begin
	counter = counter + 1;
	LCLK = ~counter[6];
	
	if(CE) begin	// if counter clock control enabled...
		if(counter_reset == 0) begin // if the counter hasn't been reset...
		  counter = 7'b1000000;      // reset the counter
		  counter_reset = 1;
		end
		I2C_CLK = counter[6]; // set the SCL according to counter. On reset it's 1
	end
	else if(I2C_CLK == 0) begin
	  I2C_CLK = counter[6];
	  counter_reset = 0;
	end
	else begin
	  counter_reset = 0;
	end
end


// state machine logic
always @ (posedge LCLK) begin
	State = Next;
	subState = subNext;
	
	case(State)
		IDLE: begin
			I2C_DATA <= 1;
			if(request & ~busy) begin
				Next <= SETUP;			  // goto SETUP state
				subNext <= ssADDR;
		    I2C_DATA <= 0;     // send start bit
				CE <= 1;
				busy <= 1;
			end
			else begin
			  busy <= 0;
			end
		end
		SETUP: begin
			case(subState)
				ssADDR: begin
					if(scl_ticks < 7) begin			// send 7-bit addr
						I2C_DATA = address[6 - scl_ticks];
					end
					else if(scl_ticks == 7) begin // send R/W = 0
						I2C_DATA <= 0;
					end
					else begin
						I2C_DATA <= 1;
						subNext <= ssSADDR;
					end
				end
				ssSADDR: begin
					if(scl_ticks < 8) begin			// send 7-bit sub addr
						I2C_DATA = sub_address[7 - scl_ticks];
					end
					else if(scl_ticks == 8) begin	// set SDA to 'Z'
					  I2C_DATA <= 1;				   // to receive ACK
						if(WR == 1) begin
							Next <= WRITE;				// goto WRITE next state execution
						end
						else begin
							Next <= READ;				// goto READ next state execution
							subNext <= ssIDLE;	
						end
					end
				end
			endcase
		end
		READ: begin
			case(subState)
				ssIDLE: begin
				  if(I2C_DATA == 0) begin // prep for start cond.		
					  I2C_DATA <= 1;
					end
					else if(CE == 1) begin
					  CE <= 0;		        // SCL = Z for repeating start cond.
					end
					else begin
					  subNext <= ssADDR;
					  I2C_DATA <= 0;       // send repeated start
					  CE <= 1;
					end
				end
				ssADDR: begin
					if(scl_ticks < 7) begin			// send 7-bit addr
						I2C_DATA = address[6 - scl_ticks];
					end
					else if(scl_ticks == 7) begin // send R/W = 1
						I2C_DATA <= 1;
					end
					else begin							            // set SDA to 'Z'
						I2C_DATA <= 1;						       // to receive ACK
						subNext <= ssRECEIVE;
					end
				end
				ssRECEIVE: begin
					if(bytes_processed < length) begin
						if(scl_ticks < 8) begin			         // receive data bit
							I2C_DATA <= 1;						             // SDA is 'Z'
						end
						else if(scl_ticks == 8) begin // send ACK/NACK
							if(bytes_processed + 1 == length) begin
								I2C_DATA <= 1; // NACK
							end
							else begin
								I2C_DATA <= 0; // ACK
							end
						end
					end
					else if(bytes_processed == length) begin
					  // setup for stop cond.
			      I2C_DATA <= 0;
			      CE <= 0;
					end
					else begin
						I2C_DATA <= 1;
						Next <= IDLE;
						subNext <= ssIDLE;
					end
				end
			endcase
		end
		WRITE: begin
			if(bytes_processed < length) begin
				if(scl_ticks < 8) begin				         // Send data bits
					I2C_DATA <= txReg[7 - scl_ticks]; // MSB first
				end
				else if(scl_ticks == 8) begin // receive ACK
				  I2C_DATA <= 1;
				end
			end
			else if(bytes_processed == length) begin
			  // setup for stop cond.
			  CE <= 0;
			  I2C_DATA <= 0;						
			end
			else begin
				I2C_DATA <= 1;
				Next <= IDLE;
				subNext <= ssIDLE;
			end
		end
	endcase
end

always @ (posedge SCL) begin
	scl_ticks = scl_ticks + 1;
	case(State)
	  IDLE: begin
	    scl_ticks = 0;
	    DE = 0;
	  end
		SETUP: begin
		  DE = 0;
			if(scl_ticks == 9) begin
				scl_ticks <= 0;
				if(SDA == 1) begin // received NACK
					//error = 1;
				end
			end
			bytes_processed <= 0;
		end
		READ: begin
			case(subState)
			  ssIDLE: begin
			    scl_ticks <= 0;
			  end
				ssADDR: begin
					if(scl_ticks == 9) begin
						scl_ticks <= 0;
						if(SDA == 1) begin // received NACK
							// indicate error here
					   end
				  end
				end
				ssRECEIVE: begin
					if(scl_ticks == 9 || CE == 0) begin
						bytes_processed = bytes_processed + 1;
						DE = 1;
						scl_ticks = 0;
					end
					else begin
						DE = 0;
						rxReg = rxReg << 1;
						rxReg[0] = SDA;
					end
				end
			endcase
		end
		WRITE: begin
			if(scl_ticks == 9 || CE == 0) begin
				scl_ticks <= 0;
				bytes_processed <= bytes_processed + 1;
				DE <= 1;
				if(SDA == 1) begin // received NACK
					// indicate error here
				end
			end
			else begin
			  DE <= 0;
			end
		end
	endcase
end

endmodule

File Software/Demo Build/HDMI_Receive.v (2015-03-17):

/*==========================================================
	File: HDMI_Receive.v

	Author: Cassandra Chow

	Copyright DigiPen Institute of Technology 2014

	Brief: Module for interfacing with the Analog Devices
	HDMI Receiver, ADV7611
==========================================================*/
module HDMI_Receive (
CLOCK_50,
SW,
KEY,
HEX0,
HEX1,
HEX4,
HEX5,
HEX6,
HEX7,
HDMI0_RX_RESET,
HDMI0_RX_HSYNC,
HDMI0_RX_VSYNC,
HDMI0_RX_MCLK,
HDMI0_RX_LRCLK,
HDMI0_RX_SCLK,
HDMI0_RX_AP,
HDMI0_RX_SCL,
HDMI0_RX_SDA,
HDMI0_RX_DE,
HDMI0_RX_LLC,
HDMI0_RX_P,
LEDG,
LEDR,
VGA_R,
VGA_G,
VGA_B,
VGA_CLK,
VGA_BLANK_N,
VGA_VS,
VGA_HS
);

input 	CLOCK_50;
input 	[17:0]SW;
input 	[3:0]KEY;
input 	[23:0]HDMI0_RX_P;		// pixel data
input		HDMI0_RX_LLC;			// line-locked pixel data clock
input		HDMI0_RX_DE;			// pixel data enable

inout		HDMI0_RX_SDA;			// I2C data line
										// -- cannot read/write at same time, assign highZ for reading
										// -- can NOT be type reg
										// -- must have a condition at which the port is written or read upon
										// -- ex) assign SDA = (condition) ? <value> : n'bZ;										
inout    HDMI0_RX_SCL;			// I2C clock line

input 	HDMI0_RX_AP;			// Audio output from chip
input 	HDMI0_RX_SCLK;			// audio serial clock
input 	HDMI0_RX_LRCLK;		// audio left-right clock
input 	HDMI0_RX_MCLK;			// audio master clock

input		HDMI0_RX_VSYNC;		// THESE ARE
input		HDMI0_RX_HSYNC;		// INPUT ONLY PINS

output reg	HDMI0_RX_RESET;		// ACTIVE LOW, resets HDMI receiver

output reg [9:0]LEDG;
output reg [18:0]LEDR;
output wire[6:0]HEX0;
output wire[6:0]HEX1;
output wire[6:0]HEX4;
output wire[6:0]HEX5;
output wire[6:0]HEX6;
output wire[6:0]HEX7;

output	  [7:0]VGA_R;
output	  [7:0]VGA_G;
output	  [7:0]VGA_B;
output     VGA_CLK;
output     VGA_BLANK_N;
output     VGA_HS;
output 	  VGA_VS;

reg		  [3:0]val0;
reg		  [3:0]val1;
reg		  [3:0]val4;
reg		  [3:0]val5;
reg		  [3:0]val6;
reg		  [3:0]val7;


To_Hex hex_display0(.bin4(val0), .display(HEX0));
To_Hex hex_display1(.bin4(val1), .display(HEX1));
To_Hex hex_display4(.bin4(val4), .display(HEX4));
To_Hex hex_display5(.bin4(val5), .display(HEX5));
To_Hex hex_display6(.bin4(val6), .display(HEX6));
To_Hex hex_display7(.bin4(val7), .display(HEX7));

reg		i2c0_wren;				// indicates r/w for i2c
reg		[7:0]i2c0_size;		// indicates r/w size in bytes for i2c
reg		i2c0_req;				// controls i2c requests
wire		i2c0_de;					// indicates when i2c data has been processed
reg		[63:0]i2c0_tx;			// transmit reg
wire		[63:0]i2c0_rx;			// receive reg
reg		[6:0]i2c0_addr;		// address    (HDMI map address)
reg		[7:0]i2c0_saddr;		// subaddress (HDMI subaddress in map)

wire		busy;
reg		de_oneshot;
reg		temp;

// i2c module
I2C receiver_i2c(.clk_50(CLOCK_50), .WR(i2c0_wren), .length(i2c0_size),
 .request(i2c0_req), .DE(i2c0_de), .SDA(HDMI0_RX_SDA), .SCL(HDMI0_RX_SCL),
 .txReg(i2c0_tx[7:0]), .rxReg(i2c0_rx[7:0]), .address(i2c0_addr), .sub_address(i2c0_saddr), .busy(busy));
 
assign VGA_R = HDMI0_RX_P[7:0];
assign VGA_G = HDMI0_RX_P[15:8];
assign VGA_B = HDMI0_RX_P[23:16];
assign VGA_CLK = HDMI0_RX_LLC;
assign VGA_BLANK_N = HDMI0_RX_DE;
assign VGA_HS = HDMI0_RX_HSYNC;
assign VGA_VS = HDMI0_RX_VSYNC;

initial begin
	i2c0_req = 0;
	i2c0_wren = 1;
	
	LEDG[8:0] = 0;
	LEDR[17:0] = 0;
	val0 = 0;
	val6 = 0;
	val7 = 0;
	
	HDMI0_RX_RESET = 1;
	de_oneshot = 0;
	temp = 0;
end

always @(posedge CLOCK_50) begin
	val0 = SW[3:0];
	val1 = SW[7:4];
	val6 = SW[13:10];
	val7 = SW[17:14];
	i2c0_saddr = SW[17:10];		// subaddress = SW17-S10
	i2c0_addr = 7'b1001100;		// IO map address = 0x98
	
	val4 = i2c0_rx[3:0];			// byte received
	val5 = i2c0_rx[7:4];
  
  if(KEY[0] == 0 && busy == 0 && temp == 0) begin			// KEY0 pressed
	 i2c0_tx[7:0] = SW[7:0];			// byte to transfer = SW7-SW0
    i2c0_wren = 1;					// perform i2c write
	 i2c0_size = 1;					// write only 1 byte
	 i2c0_req = 1;
	 temp = 1;
  end
  else if(KEY[1] == 0 && busy == 0 && temp == 0) begin		// KEY1 pressed
    i2c0_tx[7:0] = SW[7:0];			// byte to transfer = SW7-SW0
    i2c0_wren = 0;					// perform i2c read
	 i2c0_size = 1;					// read only 1 byte
	 i2c0_req = 1;
	 temp = 1;
  end
  else if(KEY[2] == 0 && busy == 0 && temp == 0) begin		// KEY2 pressed
	 i2c0_wren = 1;				// write 5 configuration bytes to IO map
	 i2c0_saddr = 0;
	 i2c0_tx[63:0] = 64'h4240F20608;
	 i2c0_size = 5;
	 i2c0_req = 1;
	 temp = 1;
  end
  else if(KEY[3] == 0) begin
	 temp = 0;
  end
  else if(busy == 1)begin
    i2c0_req = 0;
  end
  
  if(i2c0_de & !de_oneshot) begin
	i2c0_tx = i2c0_tx >> 8;
  end
  
  de_oneshot = i2c0_de;
  
  LEDG[1] = busy;
end

endmodule

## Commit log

2015-01-29 Initial Commit
    Adding all types of project files from DigiPen workspace
    [HDMI_transmitter.sch, hdmi_receiver.brd, hdmi_receiver.sch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]
2015-02-12 First Code Commit
    Fixed I²C bugs. Implemented simple interface for I²C operations using
    the buttons, switches, hex displays, and leds.
    [hdmi_receiver.brd, hdmi_receiver.sch, hdmi_transmitter.sch]
2015-03-17 Main Program Updates
    Updating main always to integrate push button actions:
    (0) Write single byte with input value to input address
    (1) Read single byte value at input address
    (2) Write 5 bytes of data for configuring HDMI to VGA
    Added code to ensure transmit register was shifted correctly between
    bytes during a single write. Fixed problem with I2C failing when
    continuous read/write are issued. Added a I2C_READY flag to ensure the
    bus is left in the IDLE state for sufficient cycles between
    transactions.
    [HDMI_Receive.v, I2C.v]
2015-04-13 Testbench update
    Updated ModelSim files and I2C module in order to test bug fixes the I2C
    protocol. Fixes need to be tested on platform.
    [I2C.v, I2C_TEST_Receive.v, I2C_TEST_Transmit.v]

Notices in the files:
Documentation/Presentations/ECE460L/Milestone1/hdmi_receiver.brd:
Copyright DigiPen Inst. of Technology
